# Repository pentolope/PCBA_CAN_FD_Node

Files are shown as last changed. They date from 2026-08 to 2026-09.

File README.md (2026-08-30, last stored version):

# CAN-FD Sensor/Control Node

General-purpose CAN-FD node for a 24 V industrial system: MCU with CAN-FD, external transceiver, switchable termination, four inputs, four low-side outputs.

This repository holds the design problem for `PCBA_CAN_FD_Node`, titled in metadata "CAN-FD Sensor/Control Node": a general-purpose CAN-FD node for a 24 V industrial system. The brief fixes the functional skeleton: a modern MCU with CAN-FD driving an external CAN-FD transceiver, switchable 120-ohm bus termination, ESD protection at the bus connector, reverse-polarity and transient protection on the 24 V input, an efficient local regulator, and four digital inputs plus four low-side outputs for demonstration loads. It also fixes one placement rule — the CAN connector must place CANH/CANL adjacent, with protection and termination kept near that connector. Everything else is open: no part, vendor, connector, package, regulator topology, rail voltage, bit rate, current rating, board outline, or stackup is named, and the layer count is only characterised in metadata as "2 or 4". The design agent must choose and justify those, documenting engineering decisions rather than treating them as pre-existing user requirements.

> **This board has not been designed.** There is no schematic, no layout and no
> part selection here — only the brief, a reading of the brief, and the
> scaffolding a design run needs. That is the intended state of this repository,
> not a gap in it.

## What the brief fixes, and what it leaves open

The brief pins down 14 requirements and deliberately leaves
20 decisions to whoever designs the board. The `Source` column says
which is which: `brief` is quoted from [BRIEF.md](BRIEF.md), `metadata` comes
from the benchmark catalogue, and `open` means the brief does not fix it.

| Aspect | Value | Source |
|---|---|---|
| Board identity | repo PCBA_CAN_FD_Node; title "CAN-FD Sensor/Control Node"; benchmark_id 6 | metadata |
| Board function | General-purpose CAN-FD node for a 24 V industrial system | brief |
| Category / difficulty / brief detail | industrial-network; difficulty 2/5; detail 3/5 | metadata |
| Likely layer count | 2 or 4 | metadata |
| Primary stressors | CAN differential pair, 24V input protection, termination, MCU clocking | metadata |
| Controller | A modern MCU with CAN-FD (no family, part or package named) | brief |
| Bus PHY | External CAN-FD transceiver, separate from the MCU | brief |
| Bus termination | Switchable 120-ohm termination | brief |
| Bus protection | ESD protection at the bus connector | brief |
| 24 V input protection | Reverse-polarity and transient protection on the 24 V input | brief |
| Local power conversion | An efficient local regulator (topology, input source, rails and ratings unstated) | brief |
| Digital inputs | Four | brief |
| Outputs | Four low-side outputs, for demonstration loads | brief |
| CAN connector arrangement and protection zone | CANH/CANL adjacent at the connector; protection and termination kept near the connector | brief |
| Board outline, connector types, rails, bit rates and specific part numbers | Not fixed by the brief - design agent's choice | open |

The full split, with the verbatim brief text substantiating every fixed
requirement, is in [board/requirements.md](board/requirements.md) and
machine-readably in [board/requirements.json](board/requirements.json).

**Missing details are design freedom, not permission to fabricate unstated user
requirements.** A choice the brief left open is recorded as a decision, with its
reasoning — never promoted into a requirement.

## Benchmark position

| | |
|---|---|
| Benchmark id | 6 of 32 |
| Category | industrial-network |
| Difficulty | 2 / 5 |
| Brief detail | 3 / 5 |
| Likely layer count | 2 or 4 |
| Primary stressors | CAN differential pair, 24V input protection, termination, MCU clocking |

At difficulty 2/5 and brief detail 3/5 in the `industrial-network` category, this board tests whether an agent can execute a well-understood industrial node without over-claiming: the named stressors are the CAN differential pair, 24 V input protection, termination, and MCU clocking. The brief is specific about block-level content and one connector-region placement rule, but deliberately silent on parts, rails, bit rates, ratings, geometry and stackup — so the benchmark measures how cleanly an agent separates the stated architecture from the many unstated choices, and whether it can substantiate a differential pair, a protection front end, and a clock accurate enough for CAN-FD bit timing with real evidence rather than assertion.

This repository is one of thirty-two. The suite, the protocol and the results
live in [PCBA_AutoDesignAndTest_Bench](https://github.com/pentolope/PCBA_AutoDesignAndTest_Bench).

## Repository layout

| Path | Contents |
|---|---|
| `BRIEF.md` | the supplied brief — authoritative, preserved byte for byte, never edited |
| `board/requirements.md` | what the brief fixes, what it leaves open, and where decisions get recorded |
| `board/requirements.json` | the same split, machine-readable, each fixed requirement bound to brief text |
| `board/manifest.template.json` | the toolkit's minimum manifest, pre-filled for this board |
| `board/toolchain.json` | where this board's build finds KiCad and the router |
| `benchmark/metadata.json` | the supplied catalogue entry — category, difficulty, detail, stressors |
| `docs/architecture.md` | the decisions this board must make, as questions, unanswered |
| `docs/sources.md` | the classes of evidence the design will have to cite |
| `docs/status.md` | what exists, what does not, and what is deliberately absent |
| `candidates/` | disposable search output, ignored by Git |
| `.claude/skills/` | the accountability-review skill [CLAUDE.md](CLAUDE.md) requires before a push |
| `tooling/PCBA_AutoDesignAndTest` | the shared verification/routing/release toolkit, as a pinned submodule |

## Getting the repository

The toolkit is a submodule and carries KiCad Routing Tools as a submodule of its
own, so clone recursively:

```bash
git clone --recursive https://github.com/pentolope/PCBA_CAN_FD_Node.git
```

```bash
git submodule update --init --recursive
```

## Designing the board

Generic verification, routing and release logic is **not** written here. It is
consumed from `tooling/PCBA_AutoDesignAndTest`, which is board-agnostic by
construction and must stay that way; this repository owns the board and nothing
else. Start from
[the toolkit's onboarding guide](tooling/PCBA_AutoDesignAndTest/examples/onboarding.md),
and see [CLAUDE.md](CLAUDE.md) for the rules a design run works under.

```bash
python3 tooling/PCBA_AutoDesignAndTest/run.py preflight
```

## Brief integrity

`BRIEF.md` SHA-256 `3897ccfaae068a75cbd3eae3186d01ac4c7f7dafd298f4a1a979556b659bc86c`

Every quotation in `board/requirements.json` is bound to those exact bytes. If
the brief ever changes, the bindings are stale by construction — which is the
point of recording the digest.

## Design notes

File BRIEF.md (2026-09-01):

# PCBA_CAN_FD_Node — CAN-FD Sensor/Control Node
## Design brief

Design a general-purpose CAN-FD node for a 24 V industrial system. Use a modern MCU with CAN-FD, an external CAN-FD transceiver, switchable 120-ohm termination, ESD protection at the bus connector, reverse-polarity and transient protection on the 24 V input, and an efficient local regulator. Provide four digital inputs and four low-side outputs for demonstration loads. The CAN connector must place CANH/CANL adjacent and keep protection/termination near the connector.

## Functional requirements

- With only the 24 V input and the CAN connector attached, the board shall pass bus traffic, read all four inputs and drive all four outputs.
- The MCU shall reach the bus only through the external transceiver; classical CAN and CAN-FD shall both be supported, and the maximum qualified data-phase rate stated.

## Power input and protection

- The continuous 24 V input range shall be stated, with every part in that path rated above it with margin.
- Reverse polarity at that magnitude shall not damage the board or latch, and transients shall be clamped below the rating of everything behind the input.
- Conversion to the logic rail(s) shall not dissipate the full input-to-output difference at load; the transceiver shall get the supply voltage its datasheet requires.

## CAN interface and termination

- CANH and CANL shall occupy adjacent connector contacts, with no other contact between them.
- Termination shall be a nominal 120 Ω differential load when enabled and switchable to fully removed without unsoldering parts.
- Bus protection shall meet the declared IEC 61000-4-2 level, be balanced line to line, and add no more capacitance than the qualified rate allows.
- The bus fault voltage withstood shall be stated and shall cover CANH or CANL shorted to ground or to the node's own 24 V.

## Digital inputs and low-side outputs

- Each input shall have a stated threshold and hysteresis and a defined state with its terminal open.
- Each input shall survive, continuously, any voltage from 0 V to the maximum rated 24 V input, in either polarity.
- Each output shall switch independently, be off from power-on until firmware drives it, and clamp inductive turn-off energy within its rating, at the stated per-channel current with all four on.

## Placement and layout

- Bus protection shall be first in the path from the connector contacts, termination immediately behind it, with no bus trace reaching elsewhere first.
- CANH/CANL shall be a coupled pair of constant spacing over an unbroken return path, with no stubs, and discharge return shall reach the connector's reference by a short, low-inductance path.

## Test and bring-up

- Programming and debug shall be on a labelled footprint usable with the board powered and the bus mated.
- Test points shall be provided on each rail, on CANH and CANL, and on the transceiver's TXD/RXD pair.

## Open choices

- MCU and transceiver selection, subject to an integrated CAN-FD controller, the I/O count above, and the declared rate and fault ratings.
- Whether termination switches manually or under MCU control, and the connector families and rail voltages that follow.

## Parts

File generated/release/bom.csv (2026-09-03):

Quantity | Designator | Comment | Footprint | LCSC Part #
1 | C1 | 47uF | Capacitor_SMD:CP_Elec_6.3x7.7 | C47023121
10 | C2,C3,C8,C10,C11,C12,C13,C15,C18,C19 | 100nF | Capacitor_SMD:C_0603_1608Metric | C113803
2 | C4,C5 | 1uF/100V | Capacitor_SMD:C_1206_3216Metric | C70463
3 | C6,C7,C9 | 10uF | Capacitor_SMD:C_0805_2012Metric | C326595
1 | C14 | 1uF | Capacitor_SMD:C_0603_1608Metric | C106858
2 | C16,C17 | 15pF | Capacitor_SMD:C_0603_1608Metric | C107037
1 | C20 | 4.7nF | Capacitor_SMD:C_0603_1608Metric | C115052
4 | C21,C22,C23,C24 | 10nF | Capacitor_SMD:C_0603_1608Metric | C107059
1 | D1 | SMAJ30CA | Diode_SMD:D_SMA | C110043
1 | D2 | BZT52C12 | Diode_SMD:D_SOD-123 | C173429
1 | D3 | B1100 | Diode_SMD:D_SMA | C110106
1 | D4 | ESDCAN05-2BWY | Package_TO_SOT_SMD:SOT-323_SC-70 | C1973137
4 | D5,D6,D7,D8 | 1N4148W | Diode_SMD:D_SOD-123 | C81598
4 | D9,D10,D11,D12 | SMF30A | CanFdNode:D_SOD-123FL_1.2x1.2mm_P3.2mm | C364281
1 | D13 | KT-0603R | LED_SMD:LED_0603_1608Metric | C2286
1 | F1 | 1812L200/33GR | CanFdNode:PTC_1812_LUTE_1812L | C18198343
1 | J1 | DB128V-5.08-2P-GN-S | CanFdNode:TerminalBlock_DB128V-5.08_1x02_P5.08mm | C2915639
1 | J2 | DB128V-5.08-3P-GN-S | CanFdNode:TerminalBlock_DB128V-5.08_1x03_P5.08mm | C2915640
2 | J3,J4 | DB128V-5.08-5P-GN-S | CanFdNode:TerminalBlock_DB128V-5.08_1x05_P5.08mm | C2927513
1 | J5 | KH-2.54PH180-1X5P-L11.5 | Connector_PinHeader_2.54mm:PinHeader_1x05_P2.54mm_Vertical | C2932699
2 | J6,J7 | KH-2.54PH180-1X2P-L11.5 | Connector_PinHeader_2.54mm:PinHeader_1x02_P2.54mm_Vertical | C2905434
1 | L1 | 47uH | CanFdNode:Inductor_Sunlord_SWPA5040 | C86617
1 | Q1 | NCE6003X | Package_TO_SOT_SMD:SOT-23 | C2934580
4 | Q2,Q3,Q4,Q5 | WST6066A | Package_TO_SOT_SMD:SOT-23 | C148352
9 | R1,R14,R15,R16,R17,R30,R31,R32,R33 | 100k | Resistor_SMD:R_0603_1608Metric | C25803
1 | R2 | 124k | Resistor_SMD:R_0603_1608Metric | C22788
1 | R3 | 23.7k | Resistor_SMD:R_0603_1608Metric | C22912
1 | R4 | 470k | Resistor_SMD:R_0603_1608Metric | C23178
1 | R5 | 56k | Resistor_SMD:R_0603_1608Metric | C23206
1 | R6 | 2.7k | Resistor_SMD:R_0603_1608Metric | C13167
6 | R7,R8,R22,R23,R24,R25 | 10k | Resistor_SMD:R_0603_1608Metric | C25804
2 | R9,R10 | 60.4R | Resistor_SMD:R_2512_6332Metric | C3994751
1 | R11 | 470R | Resistor_SMD:R_0603_1608Metric | C23179
6 | R12,R13,R26,R27,R28,R29 | 100R | Resistor_SMD:R_0603_1608Metric | C22775
4 | R18,R19,R20,R21 | 20k | Resistor_SMD:R_0603_1608Metric | C4184
1 | U1 | STM32G431KBT6 | Package_QFP:LQFP-32_7x7mm_P0.8mm | C529357
1 | U2 | TCAN1042HGVDR | Package_SO:SOIC-8_3.9x4.9mm_P1.27mm | C124014
1 | U3 | MP2459GJ-Z | Package_TO_SOT_SMD:TSOT-23-6 | C39578
1 | U4 | HT75R33-1A | Package_TO_SOT_SMD:SOT-89-3 | C53223865
1 | Y1 | 8MHz | CanFdNode:Crystal_YXC_YSX531SL_5.0x3.2mm | C19711736

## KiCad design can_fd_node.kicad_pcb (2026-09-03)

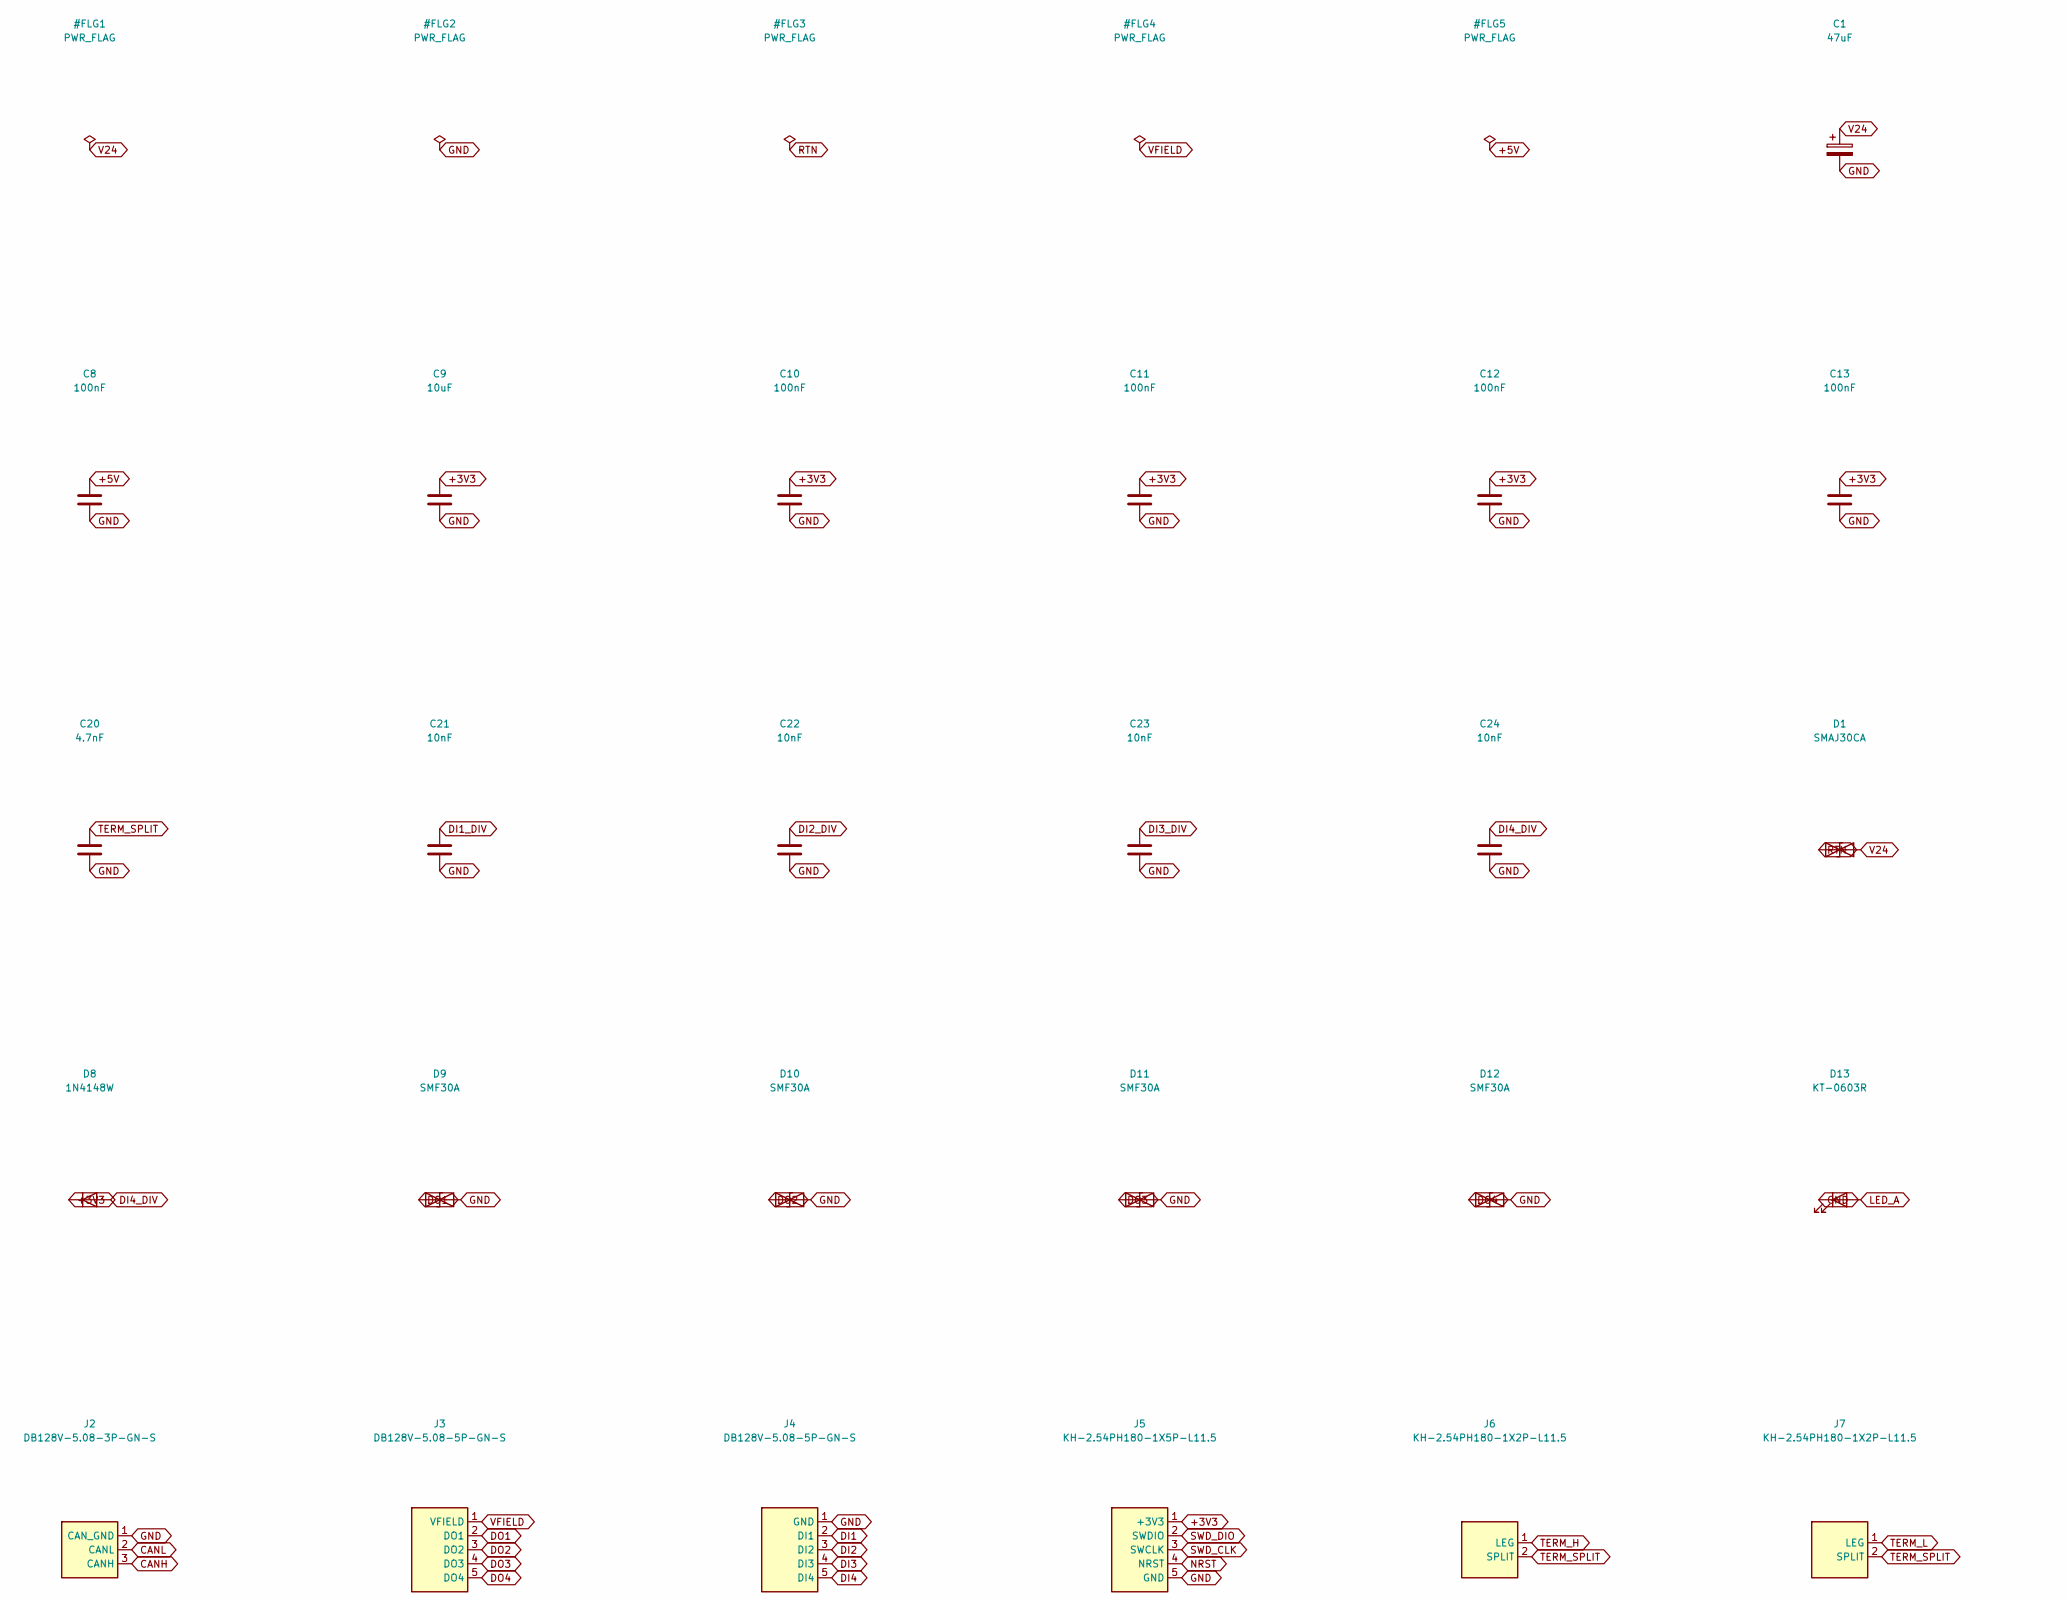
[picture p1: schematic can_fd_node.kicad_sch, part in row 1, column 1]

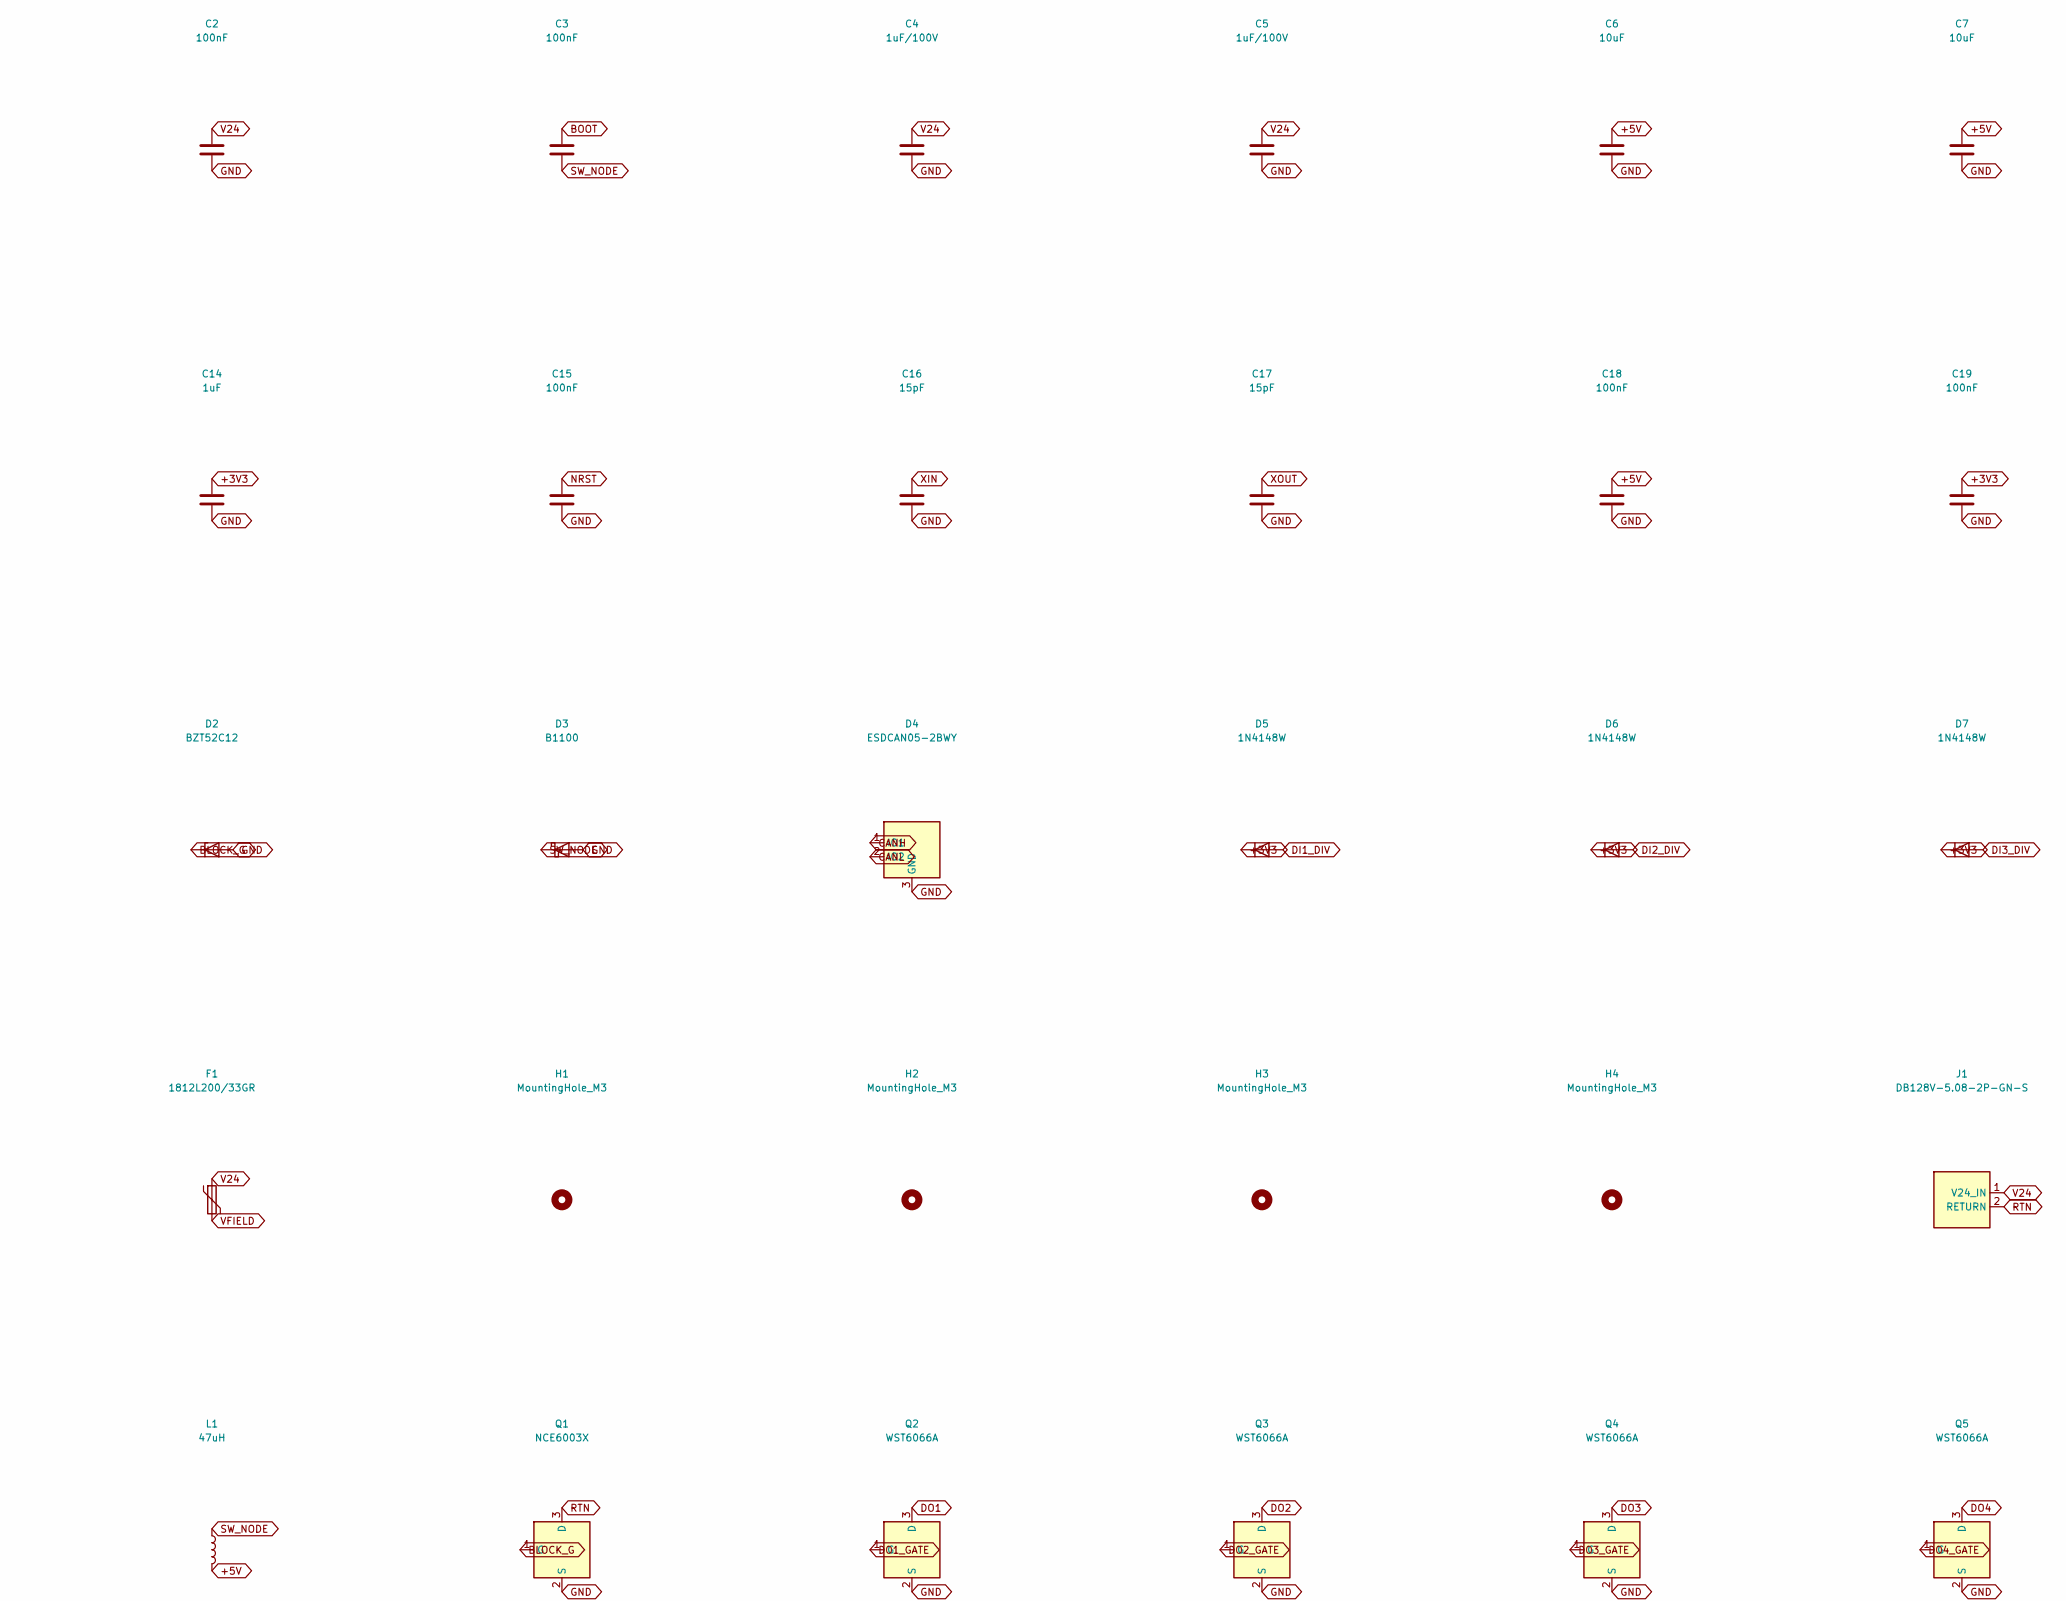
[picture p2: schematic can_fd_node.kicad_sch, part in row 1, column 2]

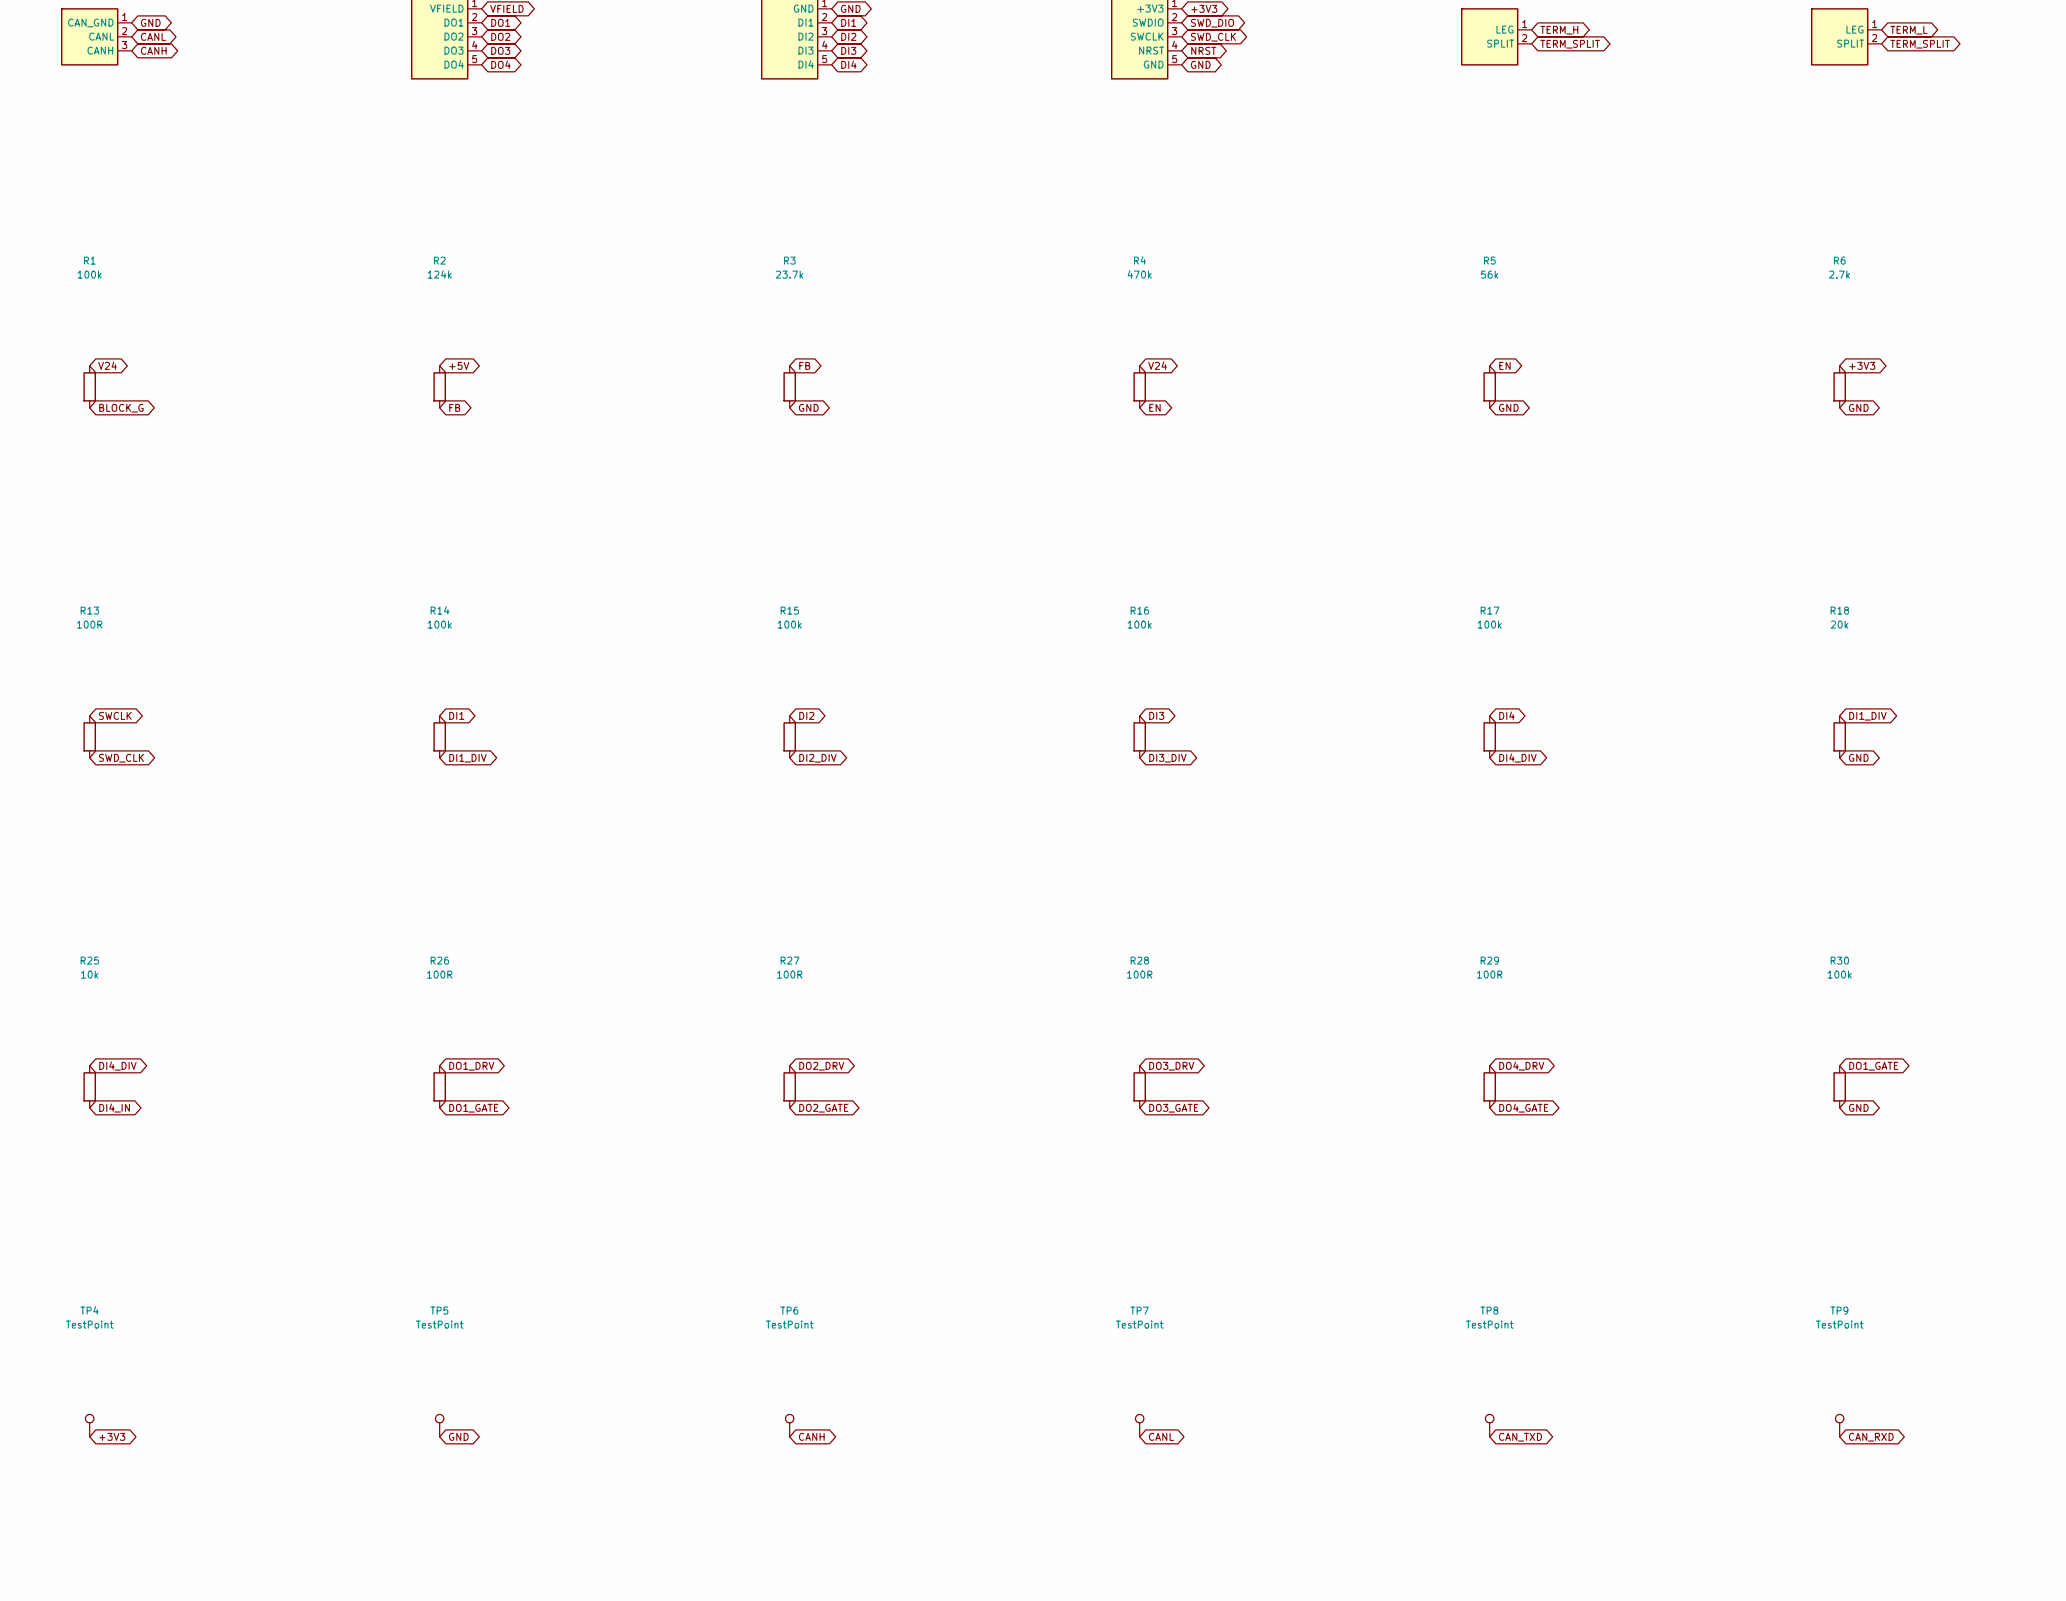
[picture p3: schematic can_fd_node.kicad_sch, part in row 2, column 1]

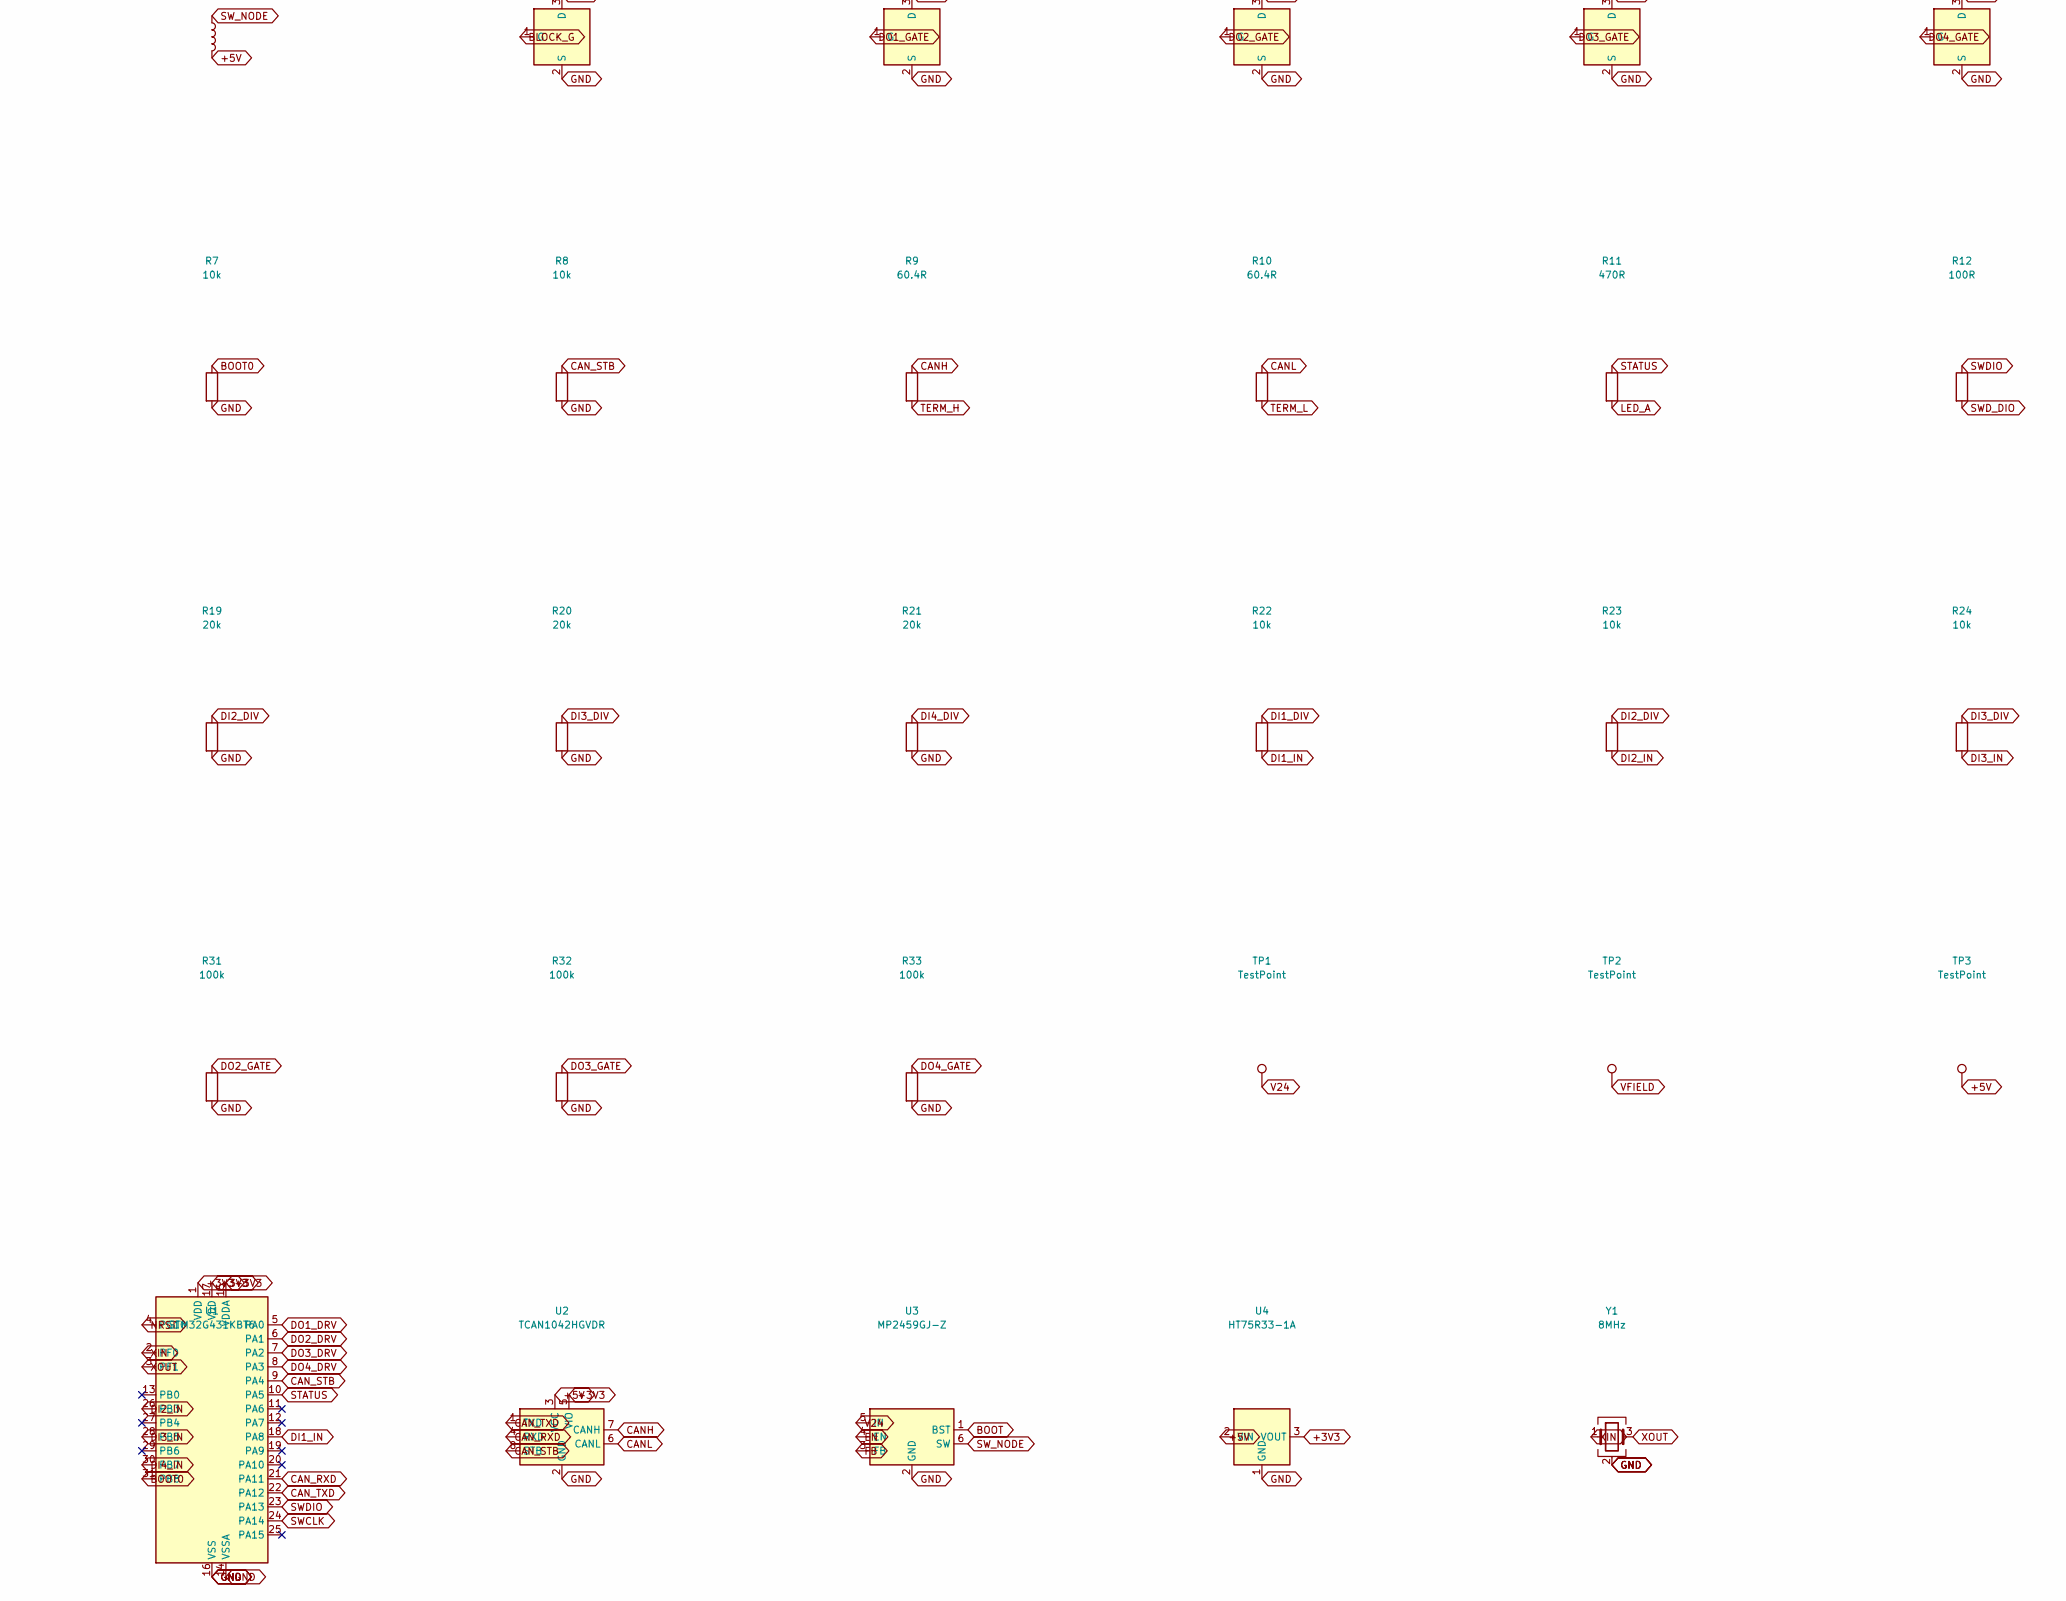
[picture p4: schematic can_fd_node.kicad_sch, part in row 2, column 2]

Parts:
C1: 47uF; CP_Elec_6.3x7.7; MPN RVT63V47M6X8; LCSC C47023121
C2, C3, C8, C10, C11, C12, C13, C15, C18, C19: 100nF; C_0603_1608Metric; MPN CC0603KRX7R0BB104; LCSC C113803
C4, C5: 1uF/100V; C_1206_3216Metric; MPN CC1206KKX7R0BB105; LCSC C70463
C6, C7, C9: 10uF; C_0805_2012Metric; MPN CC0805KKX7R7BB106; LCSC C326595
C14: 1uF; C_0603_1608Metric; MPN CC0603KRX7R8BB105; LCSC C106858
C16, C17: 15pF; C_0603_1608Metric; MPN CC0603JRNPO9BN150; LCSC C107037
C20: 4.7nF; C_0603_1608Metric; MPN CC0603KRX7R0BB472; LCSC C115052
C21, C22, C23, C24: 10nF; C_0603_1608Metric; MPN CC0603KRX7R0BB103; LCSC C107059
D1: SMAJ30CA; D_SMA; MPN SMAJ30CA; LCSC C110043
D2: BZT52C12; D_SOD-123; MPN BZT52C12; LCSC C173429
D3: B1100; D_SMA; MPN B1100-13-F; LCSC C110106
D4: ESDCAN05-2BWY; SOT-323_SC-70; MPN ESDCAN05-2BWY; LCSC C1973137
D5, D6, D7, D8: 1N4148W; D_SOD-123; MPN 1N4148W; LCSC C81598
D9, D10, D11, D12: SMF30A; D_SOD-123FL_1.2x1.2mm_P3.2mm; MPN SMF30A; LCSC C364281
D13: KT-0603R; LED_0603_1608Metric; MPN KT-0603R; LCSC C2286
F1: 1812L200/33GR; PTC_1812_LUTE_1812L; MPN 1812L200/33GR; LCSC C18198343
H1, H2, H3, H4: MountingHole_M3; MountingHole_3.2mm_M3
J1: DB128V-5.08-2P-GN-S; TerminalBlock_DB128V-5.08_1x02_P5.08mm; MPN DB128V-5.08-2P-GN-S; LCSC C2915639
J2: DB128V-5.08-3P-GN-S; TerminalBlock_DB128V-5.08_1x03_P5.08mm; MPN DB128V-5.08-3P-GN-S; LCSC C2915640
J3, J4: DB128V-5.08-5P-GN-S; TerminalBlock_DB128V-5.08_1x05_P5.08mm; MPN DB128V-5.08-5P-GN-S; LCSC C2927513
J5: KH-2.54PH180-1X5P-L11.5; PinHeader_1x05_P2.54mm_Vertical; MPN KH-2.54PH180-1X5P-L11.5; LCSC C2932699
J6, J7: KH-2.54PH180-1X2P-L11.5; PinHeader_1x02_P2.54mm_Vertical; MPN KH-2.54PH180-1X2P-L11.5; LCSC C2905434
L1: 47uH; Inductor_Sunlord_SWPA5040; MPN SWPA5040S470MT; LCSC C86617
Q1: NCE6003X; SOT-23; MPN NCE6003X; LCSC C2934580
Q2, Q3, Q4, Q5: WST6066A; SOT-23; MPN WST6066A; LCSC C148352
R1, R14, R15, R16, R17, R30, R31, R32, R33: 100k; R_0603_1608Metric; MPN 0603WAF1003T5E; LCSC C25803
R2: 124k; R_0603_1608Metric; MPN 0603WAF1243T5E; LCSC C22788
R3: 23.7k; R_0603_1608Metric; MPN 0603WAF2372T5E; LCSC C22912
R4: 470k; R_0603_1608Metric; MPN 0603WAF4703T5E; LCSC C23178
R5: 56k; R_0603_1608Metric; MPN 0603WAF5602T5E; LCSC C23206
R6: 2.7k; R_0603_1608Metric; MPN 0603WAF2701T5E; LCSC C13167
R7, R8, R22, R23, R24, R25: 10k; R_0603_1608Metric; MPN 0603WAF1002T5E; LCSC C25804
R9, R10: 60.4R; R_2512_6332Metric; MPN RMCF2512FT60R4; LCSC C3994751
R11: 470R; R_0603_1608Metric; MPN 0603WAF4700T5E; LCSC C23179
R12, R13, R26, R27, R28, R29: 100R; R_0603_1608Metric; MPN 0603WAF1000T5E; LCSC C22775
R18, R19, R20, R21: 20k; R_0603_1608Metric; MPN 0603WAF2002T5E; LCSC C4184
TP1, TP2, TP3, TP4, TP5, TP6, TP7, TP8, TP9: TestPoint; TestPoint_Pad_D1.0mm
U1: STM32G431KBT6; LQFP-32_7x7mm_P0.8mm; MPN STM32G431KBT6; LCSC C529357
U2: TCAN1042HGVDR; SOIC-8_3.9x4.9mm_P1.27mm; MPN TCAN1042HGVDR; LCSC C124014
U3: MP2459GJ-Z; TSOT-23-6; MPN MP2459GJ-Z; LCSC C39578
U4: HT75R33-1A; SOT-89-3; MPN HT75R33-1A; LCSC C53223865
Y1: 8MHz; Crystal_YXC_YSX531SL_5.0x3.2mm; MPN XL1EL89CMI-111YLC-8M; LCSC C19711736

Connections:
+3V3: C9.1, C10.1, C11.1, C12.1, C13.1, C14.1, C19.1, D5.1 (K), D6.1 (K), D7.1 (K), D8.1 (K), J5.1 (+3V3), R6.1, TP4.1, U1.1 (VDD), U1.15 (VDDA), U1.17 (VDD), U2.5 (VIO), U4.3 (VOUT)
+5V: C6.1, C7.1, C8.1, C18.1, L1.2, R2.1, TP3.1, U2.3 (VCC), U4.2 (VIN)
BLOCK_G: D2.1 (K), Q1.1 (G), R1.2
BOOT: C3.1, U3.1 (BST)
BOOT0: R7.1, U1.31 (PB8)
CANH: D4.1 (IO1), J2.3 (CANH), R9.1, TP6.1, U2.7 (CANH)
CANL: D4.2 (IO2), J2.2 (CANL), R10.1, TP7.1, U2.6 (CANL)
CAN_RXD: TP9.1, U1.21 (PA11), U2.4 (RXD)
CAN_STB: R8.1, U1.9 (PA4), U2.8 (STB)
CAN_TXD: TP8.1, U1.22 (PA12), U2.1 (TXD)
DI1: J4.2 (DI1), R14.1
DI1_DIV: C21.1, D5.2 (A), R14.2, R18.1, R22.1
DI1_IN: R22.2, U1.18 (PA8)
DI2: J4.3 (DI2), R15.1
DI2_DIV: C22.1, D6.2 (A), R15.2, R19.1, R23.1
DI2_IN: R23.2, U1.26 (PB3)
DI3: J4.4 (DI3), R16.1
DI3_DIV: C23.1, D7.2 (A), R16.2, R20.1, R24.1
DI3_IN: R24.2, U1.28 (PB5)
DI4: J4.5 (DI4), R17.1
DI4_DIV: C24.1, D8.2 (A), R17.2, R21.1, R25.1
DI4_IN: R25.2, U1.30 (PB7)
DO1: D9.1 (A1), J3.2 (DO1), Q2.3 (D)
DO1_DRV: R26.1, U1.5 (PA0)
DO1_GATE: Q2.1 (G), R26.2, R30.1
DO2: D10.1 (A1), J3.3 (DO2), Q3.3 (D)
DO2_DRV: R27.1, U1.6 (PA1)
DO2_GATE: Q3.1 (G), R27.2, R31.1
DO3: D11.1 (A1), J3.4 (DO3), Q4.3 (D)
DO3_DRV: R28.1, U1.7 (PA2)
DO3_GATE: Q4.1 (G), R28.2, R32.1
DO4: D12.1 (A1), J3.5 (DO4), Q5.3 (D)
DO4_DRV: R29.1, U1.8 (PA3)
DO4_GATE: Q5.1 (G), R29.2, R33.1
EN: R4.2, R5.1, U3.4 (EN)
FB: R2.2, R3.1, U3.3 (FB)
GND: C1.2, C2.2, C4.2, C5.2, C6.2, C7.2, C8.2, C9.2, C10.2, C11.2, C12.2, C13.2, C14.2, C15.2, C16.2, C17.2, C18.2, C19.2, C20.2, C21.2, C22.2, C23.2, C24.2, D2.2 (A), D3.2 (A), D4.3 (GND), D9.2 (A2), D10.2 (A2), D11.2 (A2), D12.2 (A2), D13.1 (K), J2.1 (CAN_GND), J4.1 (GND), J5.5 (GND), Q1.2 (S), Q2.2 (S), Q3.2 (S), Q4.2 (S), Q5.2 (S), R3.2, R5.2, R6.2, R7.2, R8.2, R18.2, R19.2, R20.2, R21.2, R30.2, R31.2, R32.2, R33.2, TP5.1, U1.14 (VSSA), U1.16 (VSS), U1.32 (VSS), U2.2 (GND), U3.2 (GND), U4.1 (GND), Y1.2 (G), Y1.4 (G)
LED_A: D13.2 (A), R11.2
NRST: C15.1, J5.4 (NRST), U1.4 (PG10)
RTN: D1.1 (A1), J1.2 (RETURN), Q1.3 (D)
STATUS: R11.1, U1.10 (PA5)
SWCLK: R13.1, U1.24 (PA14)
SWDIO: R12.1, U1.23 (PA13)
SWD_CLK: J5.3 (SWCLK), R13.2
SWD_DIO: J5.2 (SWDIO), R12.2
SW_NODE: C3.2, D3.1 (K), L1.1, U3.6 (SW)
TERM_H: J6.1 (LEG), R9.2
TERM_L: J7.1 (LEG), R10.2
TERM_SPLIT: C20.1, J6.2 (SPLIT), J7.2 (SPLIT)
V24: C1.1, C2.1, C4.1, C5.1, D1.2 (A2), F1.1, J1.1 (V24_IN), R1.1, R4.1, TP1.1, U3.5 (IN)
VFIELD: F1.2, J3.1 (VFIELD), TP2.1
XIN: C16.1, U1.2 (PF0), Y1.1
XOUT: C17.1, U1.3 (PF1), Y1.3

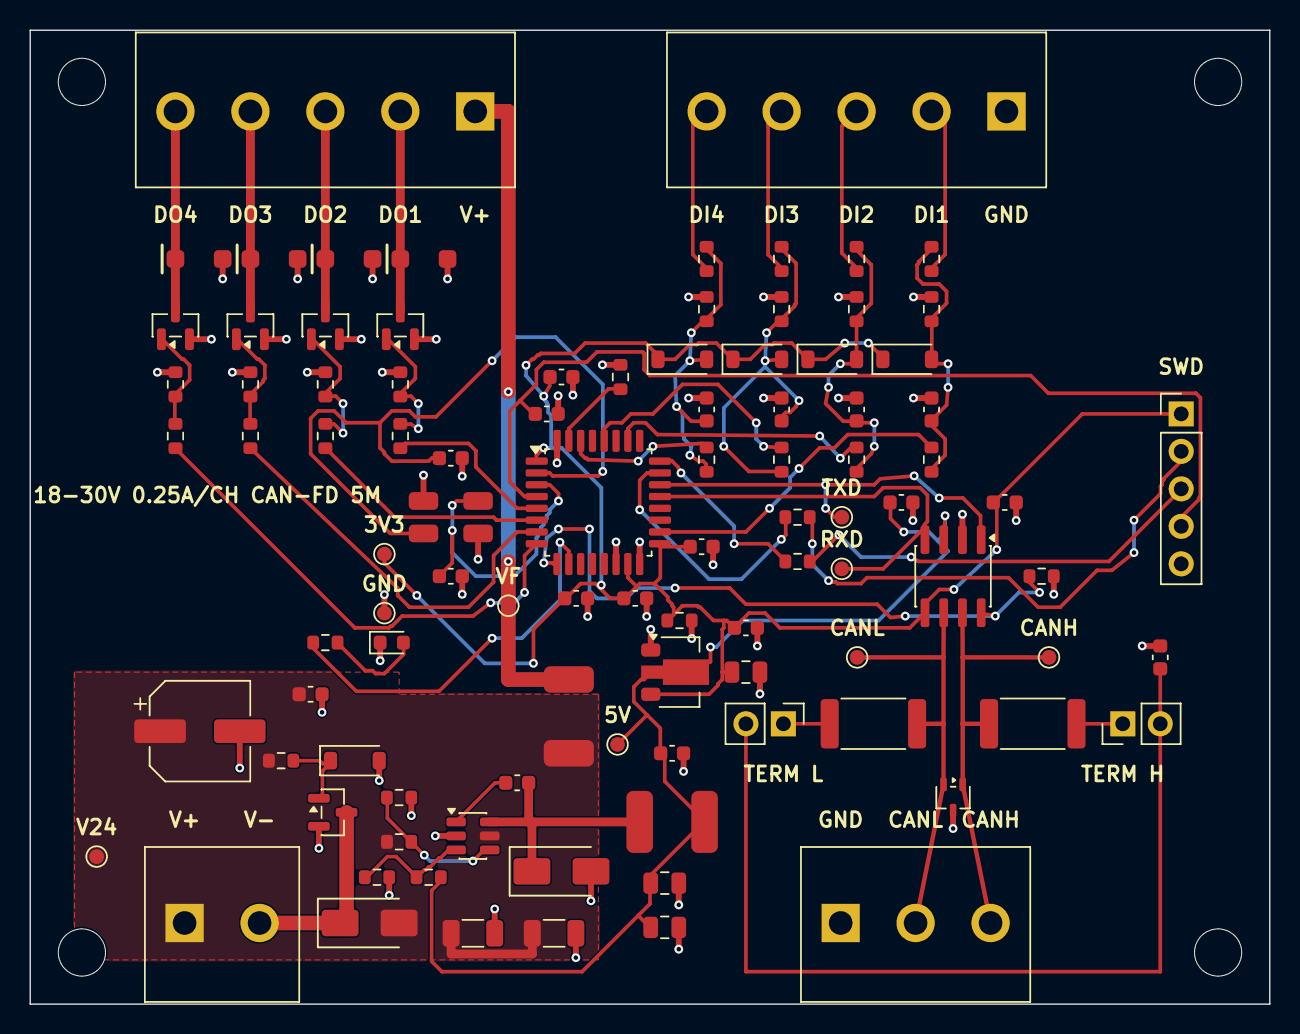
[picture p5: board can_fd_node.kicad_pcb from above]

Board: 2 copper layers, 84.0 x 66.0 mm, 102 parts (0 on the bottom side), 53 nets.

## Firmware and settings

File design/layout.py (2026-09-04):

"""The board: outline, placement, pours and silkscreen, from the design source.

Board coordinates run x right and y UP from the lower-left corner, which is
the frame every dimension in this module is stated in. KiCad's own y runs
down, so the mapping is applied once, here.

The arrangement follows the two things that must not be compromised. The bus
enters at the bottom right and meets its protection, then its termination,
then the transceiver, in that order and in a straight line, over ground that
nothing is allowed to cut. Everything the field carries enters at the two
edges: the supply and the bus along the bottom, the field inputs and outputs
along the top, so no field conductor crosses the controller. The controller
sits between them, and the power chain runs along the bottom-left from the
supply terminal to the two logic rails.
"""
from __future__ import annotations

import json
import math
import os
import sys

from . import ksym, netlist

_TOOLKIT = os.path.join(
    os.path.dirname(os.path.dirname(os.path.abspath(__file__))),
    "tooling", "PCBA_AutoDesignAndTest")
if _TOOLKIT not in sys.path:
    sys.path.insert(0, _TOOLKIT)

from pcbqa import headless  # noqa: E402

headless.suppress_blocking_ui()

from pcbqa import board as pcbqa_board  # noqa: E402

import pcbnew  # noqa: E402

REPO_ROOT = os.path.dirname(os.path.dirname(os.path.abspath(__file__)))
BOARD_PATH = os.path.join(REPO_ROOT, netlist.PROJECT_NAME + ".kicad_pcb")
PLACEMENT_PATH = os.path.join(REPO_ROOT, "constraints", "placement.json")

FOOTPRINT_SEARCH_PATHS = (
    os.path.join(REPO_ROOT, "library"),
    "/usr/share/kicad/footprints",
)

ORIGIN_MM = (30.0, 110.0)

BOARD_W_MM = 84.0
BOARD_H_MM = 66.0

EDGE_WIDTH_MM = 0.1
TRACK_WIDTH_MM = 0.25
#: Width of the generated field-supply and field-output conductors. Sized for
#: one channel's rating and, on the supply, for all four at once.
POWER_TRACK_WIDTH_MM = 0.6
FIELD_TRACK_WIDTH_MM = 1.0
#: Width of the generated bus pair, and the gap between the two conductors.
#: The pair is drawn rather than searched: constant spacing over unbroken
#: ground is a requirement, and a search has no freedom left inside it.
BUS_TRACK_WIDTH_MM = 0.3
BUS_GAP_MM = 0.3
CLEARANCE_MM = 0.15
EDGE_CLEARANCE_MM = 0.3
VIA_DIAMETER_MM = 0.6
VIA_DRILL_MM = 0.3
ZONE_INSET_MM = 0.5
STITCH_TRACK_WIDTH_MM = 0.4
#: How far a stitch's own annulus stands off the pad it bonds to. It is a
#: mask-opening figure, not a copper one: a via whose annulus touches the
#: opening of a pad that receives paste is a place for solder to wick away
#: down the barrel, and the board's own via-to-mask target is what this
#: keeps.
STITCH_GAP_MM = 0.45
#: The board's own via-to-mask-opening target, which a generated via is
#: held to as well as a routed one.
VIA_MASK_TARGET_MM = 0.15

#: Field terminal blocks sit with their wire entry on the board edge; the pin
#: row stands this far inside it.
TERMINAL_PIN_INSET_MM = 5.5
TERMINAL_PITCH_MM = 5.08

#: Where each connector's pin row sits.
BOTTOM_ROW_Y_MM = TERMINAL_PIN_INSET_MM
TOP_ROW_Y_MM = BOARD_H_MM - TERMINAL_PIN_INSET_MM

#: The one lane between the crystal and the controller. The field supply
#: runs up it, which is the only way it reaches the output connector's
#: supply contact without crossing a channel.
FIELD_CORRIDOR_X_MM = 32.4

SUPPLY_TERMINAL_X_MM = 12.0
BUS_TERMINAL_X_MM = 60.0
OUTPUT_TERMINAL_X_MM = 20.0
INPUT_TERMINAL_X_MM = 56.0

#: The bus corridor: the pair runs straight up this line from the connector,
#: through the protection and the termination tap, to the transceiver. The
#: corridor is the midpoint of the connector's own two bus contacts, so the
#: fan-in from the terminal block's 5.08 pitch is symmetric.
BUS_CORRIDOR_X_MM = BUS_TERMINAL_X_MM + TERMINAL_PITCH_MM / 2.0
#: Separation of the two conductors, which is the transceiver's own pad
#: separation: the pair arrives at the pads it is drawn for and nothing has
#: to fan out at the end of the run.
BUS_PAIR_SEPARATION_MM = 1.27
BUS_PROTECTOR_Y_MM = 14.0
BUS_TERMINATION_Y_MM = 19.0
BUS_LINK_X_OFFSET_MM = 11.5
BUS_TRANSCEIVER_Y_MM = 29.0
#: The centre of the split termination carries no differential current, so
#: it is the one conductor that may take the long way round: it runs along
#: the bottom of the board, below the connector's contacts, where it crosses
#: neither bus conductor.
BUS_SPLIT_RETURN_Y_MM = 2.2

#: The back-layer copper under the pair, between one station and the next.
#: Nothing may cut it, so the stretches between the parts are rule areas
#: rather than a hope. The stations themselves are left out, and so is the
#: stretch immediately below the protector: that is where the protector's
#: own reference via goes, and a via on the reference net ties the pour
#: together rather than cutting it - which is the whole point of the short
#: return path the brief asks for there.
BUS_KEEPOUT_HALF_WIDTH_MM = 1.6
BUS_KEEPOUT_SPANS_MM = ((8.0, 11.2), (15.7, 17.6), (20.4, 22.4),
                        (24.6, BUS_TRANSCEIVER_Y_MM - 3.2))

#: Rows inside a field-output column, from the connector down.
OUTPUT_ROWS_MM = {"clamp": 50.5, "switch": 46.0, "gate": 42.0,
                  "series": 38.5}
#: Rows inside a field-input column, from the connector down.
INPUT_ROWS_MM = {"upper": 50.5, "lower": 47.1, "clamp": 43.7,
                 "filter": 40.3, "series": 36.9}
#: How far a channel's clamp stands off its own lane. The clamp's other
#: terminal is the reference, and it belongs beside the lane rather than in
#: it: the conductor that carries the channel's current runs straight up the
#: lane through the clamp's first pad and reaches the contact without
#: stepping round anything.
OUTPUT_CLAMP_OFFSET_MM = 1.60
INPUT_CLAMP_OFFSET_MM = -1.65

MOUNTING_HOLES_MM = {
    "H1": (3.5, 3.5),
    "H2": (BOARD_W_MM - 3.5, 3.5),
    "H3": (3.5, BOARD_H_MM - 3.5),
    "H4": (BOARD_W_MM - 3.5, BOARD_H_MM - 3.5),
}

#: Parts a placement search may not move, and why.
#:
#: The connectors and the fasteners are the board's mechanical contract. The
#: test points are its service contract. The bus protector, the termination
#: and the transceiver are the one chain whose order the brief fixes, and the
#: pair between them is generated copper, so their positions are the topology
#: rather than an input to it.
LOCKED_REFERENCES = tuple(sorted(
    [reference for reference in netlist.PARTS
     if reference[0] in ("J", "H") and reference[1:].isdigit()]
    + [reference for reference in netlist.PARTS
       if reference.startswith("TP")]
    + ["U2", "D4", "R9", "R10", "C20"]))


def connector_pin_x(reference, pin):
    """Where one contact of a bottom- or top-edge terminal block sits.

    The top-edge blocks face outward, so they are turned round and their
    contacts run right to left. A channel column stands under its own
    contact, so the column positions are read from here rather than declared
    a second time and left to drift.
    """
    centre, _y, rotation = SHARED_PLACEMENT[reference]
    count = len(netlist.CONNECTOR_PIN_ORDER[reference])
    span = TERMINAL_PITCH_MM * (count - 1) / 2.0
    offset = -span + TERMINAL_PITCH_MM * (pin - 1)
    return centre + (offset if rotation == 0.0 else -offset)


def _output_lane_x(channel):
    return connector_pin_x("J3", channel + 1)


def _input_lane_x(channel):
    return connector_pin_x("J4", channel + 1)


def _output_seed(channel):
    """One field-output column: clamp, switch, then the gate network.

    Every part stands in the 5.08 lane its own contact occupies, so a
    channel's current never crosses another channel's.
    """
    x = _output_lane_x(channel)
    rows = OUTPUT_ROWS_MM
    return {
        "D%d" % (channel + 8): (x + OUTPUT_CLAMP_OFFSET_MM, rows["clamp"],
                                0.0),
        "Q%d" % (channel + 1): (x, rows["switch"], 90.0),
        "R%d" % (channel + 29): (x, rows["gate"], 90.0),
        "R%d" % (channel + 25): (x, rows["series"], 90.0),
    }


def _input_seed(channel):
    """One field-input column: divider, clamp, filter and series element."""
    x = _input_lane_x(channel)
    rows = INPUT_ROWS_MM
    return {
        "R%d" % (channel + 13): (x, rows["upper"], 90.0),
        "R%d" % (channel + 17): (x, rows["lower"], 90.0),
        "D%d" % (channel + 4): (x + INPUT_CLAMP_OFFSET_MM, rows["clamp"],
                                0.0),
        "C%d" % (channel + 20): (x, rows["filter"], 90.0),
        "R%d" % (channel + 21): (x, rows["series"], 90.0),
    }


#: Everything that is not part of a field channel, left to right and bottom
#: to top: the supply terminal and its protection, the converter and its
#: regulator, the controller and its crystal, and the bus chain.
SHARED_PLACEMENT = {
    # the supply terminal, its clamp and the reverse-blocking device, which
    # sits in the return so the bus connector's reference pin can be the
    # board's own
    "J1": (13.0, BOTTOM_ROW_Y_MM, 0.0),
    "D1": (23.0, BOTTOM_ROW_Y_MM, 0.0),
    "Q1": (20.5, 13.0, 0.0),
    "R1": (17.0, 16.5, 0.0),
    "D2": (22.0, 16.5, 0.0),
    "C1": (11.5, 18.5, 0.0),
    "C2": (19.0, 21.0, 0.0),
    "TP1": (4.5, 10.0, 0.0),
    # the step-down converter. Its order along the board is the order of the
    # switching loop: the input capacitors, the converter, the catch diode,
    # the inductor, the output capacitors. The loop that carries the
    # switched current is the input capacitors, the converter's input and
    # switch pins, the diode and the reference, and it is that loop, not the
    # schematic, that decides these positions: the diode stands one
    # footprint from the converter and directly above the input capacitors,
    # so the loop encloses a few square millimetres of the reference plane
    # beneath it rather than the width of the board.
    "C4": (30.0, 4.8, 0.0),
    "C5": (35.5, 4.8, 0.0),
    "U3": (30.0, 11.4, 0.0),
    "R4": (25.0, 11.0, 0.0),
    "R5": (25.0, 14.0, 0.0),
    "D3": (36.0, 9.0, 0.0),
    "L1": (43.5, 12.35, 0.0),
    "C3": (33.0, 15.0, 0.0),
    # the feedback divider stands away from the switch node and the
    # bootstrap capacitor, on the quiet side of the converter, so the node
    # the converter regulates on runs beside neither of them. What is long
    # is instead the sense conductor from the output, which is a rail.
    "R2": (27.0, 8.6, 180.0),
    "R3": (23.5, 8.6, 0.0),
    # the output capacitors stay clear of the lane the termination's centre
    # node comes down in, which owns the column outboard of the links
    "C6": (43.0, 5.2, 0.0),
    "C7": (43.0, 8.2, 0.0),
    "C8": (43.5, 17.0, 0.0),
    "TP3": (39.8, 17.6, 0.0),
    # the logic regulator and the indicator
    "U4": (44.0, 22.5, 0.0),
    "C9": (48.5, 22.5, 0.0),
    "C10": (48.5, 25.5, 0.0),
    "R6": (44.0, 26.0, 0.0),
    "TP4": (24.0, 30.5, 0.0),
    "TP5": (24.0, 26.5, 0.0),
    "R11": (20.0, 24.5, 0.0),
    "D13": (24.5, 24.5, 0.0),
    # the controller, its crystal and its debug port
    "U1": (38.5, 34.0, 0.0),
    "C11": (36.0, 42.5, 0.0),
    "C12": (45.5, 31.0, 0.0),
    "C13": (37.0, 27.5, 0.0),
    "C14": (41.0, 27.5, 0.0),
    "C15": (35.0, 40.0, 0.0),
    "Y1": (28.5, 33.0, 0.0),
    "C16": (28.5, 37.0, 0.0),
    "C17": (28.5, 29.0, 0.0),
    "R7": (40.0, 42.5, 90.0),
    "R12": (52.0, 33.0, 0.0),
    "R13": (52.0, 30.0, 0.0),
    "J5": (78.0, 40.0, 0.0),
    # the bus: connector, protection, termination, transceiver, in that
    # order up one corridor. The protector's reference pad faces the
    # connector, so the discharge it diverts returns to the contact it came
    # from over the shortest path the geometry allows.
    "J2": (BUS_TERMINAL_X_MM, BOTTOM_ROW_Y_MM, 0.0),
    "D4": (BUS_CORRIDOR_X_MM, BUS_PROTECTOR_Y_MM, 270.0),
    "R10": (BUS_CORRIDOR_X_MM - 5.4, BUS_TERMINATION_Y_MM, 180.0),
    "R9": (BUS_CORRIDOR_X_MM + 5.4, BUS_TERMINATION_Y_MM, 0.0),
    "J7": (BUS_CORRIDOR_X_MM - BUS_LINK_X_OFFSET_MM,
           BUS_TERMINATION_Y_MM, 270.0),
    "J6": (BUS_CORRIDOR_X_MM + BUS_LINK_X_OFFSET_MM,
           BUS_TERMINATION_Y_MM, 90.0),
    "TP7": (BUS_CORRIDOR_X_MM - 6.5, 23.5, 0.0),
    "TP6": (BUS_CORRIDOR_X_MM + 6.5, 23.5, 0.0),
    "C20": (BUS_CORRIDOR_X_MM + BUS_LINK_X_OFFSET_MM + 2.54, 23.5, 90.0),
    "U2": (BUS_CORRIDOR_X_MM, BUS_TRANSCEIVER_Y_MM, 270.0),
    "C18": (BUS_CORRIDOR_X_MM - 3.5, BUS_TRANSCEIVER_Y_MM + 5.0, 0.0),
    "C19": (BUS_CORRIDOR_X_MM + 3.5, BUS_TRANSCEIVER_Y_MM + 5.0, 0.0),
    "R8": (BUS_CORRIDOR_X_MM + 6.0, BUS_TRANSCEIVER_Y_MM, 0.0),
    "TP8": (55.0, 33.0, 0.0),
    "TP9": (55.0, 29.5, 0.0),
    # the field connectors and the field supply path. The supply contact is
    # the one at the turned-round block's right-hand end, so the fuse that
    # feeds it stands to the right of the output columns and its conductor
    # crosses no channel.
    "J3": (OUTPUT_TERMINAL_X_MM, TOP_ROW_Y_MM, 180.0),
    "J4": (INPUT_TERMINAL_X_MM, TOP_ROW_Y_MM, 180.0),
    "F1": (36.5, 19.5, 90.0),
    "TP2": (FIELD_CORRIDOR_X_MM, 27.0, 0.0),
}


def to_board(x_mm, y_mm):
    return (ORIGIN_MM[0] + x_mm, ORIGIN_MM[1] - y_mm)


def _point(x_mm, y_mm):
    bx, by = to_board(x_mm, y_mm)
    return pcbnew.VECTOR2I(pcbnew.FromMM(bx), pcbnew.FromMM(by))


def accepted_placement():
    """The placement a search accepted, if one has been recorded.

    Absent, the seed below is the placement. Present, it replaces the seed
    for every part that is not locked - a locked part is locked in the board
    file and the search cannot have moved it, so accepting one from this file
    would be accepting a value that never came from a search.
    """
    if not os.path.isfile(PLACEMENT_PATH):
        return {}
    with open(PLACEMENT_PATH, encoding="utf-8") as handle:
        document = json.load(handle)
    return {reference: tuple(pose)
            for reference, pose in document["placement"].items()
            if reference not in LOCKED_REFERENCES}


def seed_placement():
    placed = dict(SHARED_PLACEMENT)
    for reference, (x, y) in MOUNTING_HOLES_MM.items():
        placed[reference] = (x, y, 0.0)
    for channel in range(1, netlist.OUTPUT_COUNT + 1):
        placed.update(_output_seed(channel))
    for channel in range(1, netlist.INPUT_COUNT + 1):
        placed.update(_input_seed(channel))
    return placed


def fixed_placements():
    placed = seed_placement()
    for reference, pose in accepted_placement().items():
        if reference not in placed:
            raise KeyError("accepted placement names an unknown part: "
                           + reference)
        placed[reference] = pose
    missing = sorted(reference for reference, part in netlist.PARTS.items()
                     if part["footprint"] and reference not in placed)
    if missing:
        raise KeyError("no placement for " + ", ".join(missing))
    return placed


def _footprint_dir(footprint):
    library, _, name = footprint.partition(":")
    for base in FOOTPRINT_SEARCH_PATHS:
        candidate = os.path.join(base, library + ".pretty")
        if os.path.isfile(os.path.join(candidate, name + ".kicad_mod")):
            return candidate, name
    raise FileNotFoundError(footprint)


_PIN_NAMES = {}


def _pin_name(lib_id, number):
    if lib_id not in _PIN_NAMES:
        library = ksym.Library(netlist.SYMBOL_LIBRARY_PATHS)
        _PIN_NAMES[lib_id] = {
            key: pins[0].name for key, pins in library.pins(lib_id).items()}
    return _PIN_NAMES[lib_id].get(number, "")


def _floating_net(board, reference, number):
    lib_id = netlist.PARTS[reference]["lib_id"]
    name = "unconnected-(%s-%s-Pad%s)" % (
        reference, _pin_name(lib_id, number).replace("/", "{slash}"), number)
    existing = board.GetNetInfo().GetNetItem(name)
    if existing is not None and existing.GetNetCode() != 0:
        return existing
    net = pcbnew.NETINFO_ITEM(board, name)
    board.Add(net)
    return net


def _load(board, reference, part, x, y, rotation, pin_net, nets):
    library_dir, name = _footprint_dir(part["footprint"])
    footprint = pcbnew.FootprintLoad(library_dir, name)
    if footprint is None:
        raise RuntimeError("could not load " + part["footprint"])
    library = part["footprint"].partition(":")[0]
    footprint.SetFPID(pcbnew.LIB_ID(library, name))
    footprint.SetPosition(_point(x, y))
    footprint.SetOrientationDegrees(rotation)
    footprint.SetReference(reference)
    footprint.SetValue(part["value"])
    footprint.Reference().SetLayer(pcbnew.F_Fab)
    footprint.Value().SetLayer(pcbnew.F_Fab)
    for key, value in (("MPN", part["mpn"]), ("LCSC", part["lcsc"]),
                       ("Manufacturer", part["manufacturer"])):
        if not value:
            continue
        footprint.SetField(key, value)
        for field in footprint.GetFields():
            if field.GetName() == key:
                field.SetLayer(pcbnew.F_Fab)
                field.SetVisible(False)
    if not part["in_bom"]:
        footprint.SetExcludedFromBOM(True)
    if reference in LOCKED_REFERENCES:
        footprint.SetLocked(True)
    for pad in footprint.Pads():
        number = pad.GetNumber()
        if not number:
            continue
        net_name = pin_net.get("%s.%s" % (reference, number))
        if net_name:
            pad.SetNet(nets[net_name])
        else:
            pad.SetNet(_floating_net(board, reference, number))
    board.Add(footprint)
    return footprint


def _nets(board):
    created = {}
    for name in sorted(netlist.NETS):
        net = pcbnew.NETINFO_ITEM(board, name)
        board.Add(net)
        created[name] = net
    return created


def _design_settings(board):
    board.SetCopperLayerCount(2)
    settings = board.GetDesignSettings()
    settings.m_TrackMinWidth = pcbnew.FromMM(0.15)
    settings.m_ViasMinSize = pcbnew.FromMM(0.45)
    settings.m_MinThroughDrill = pcbnew.FromMM(0.25)
    settings.m_CopperEdgeClearance = pcbnew.FromMM(EDGE_CLEARANCE_MM)
    settings.m_HoleClearance = pcbnew.FromMM(0.25)
    settings.m_HoleToHoleMin = pcbnew.FromMM(0.25)
    settings.m_ViasMinAnnularWidth = pcbnew.FromMM(0.1)
    settings.m_MinClearance = pcbnew.FromMM(CLEARANCE_MM)
    default_class = settings.m_NetSettings.GetDefaultNetclass()
    default_class.SetClearance(pcbnew.FromMM(CLEARANCE_MM))
    default_class.SetTrackWidth(pcbnew.FromMM(TRACK_WIDTH_MM))
    default_class.SetViaDiameter(pcbnew.FromMM(VIA_DIAMETER_MM))
    default_class.SetViaDrill(pcbnew.FromMM(VIA_DRILL_MM))


def _add_outline(board):
    corners = [(0.0, 0.0), (BOARD_W_MM, 0.0), (BOARD_W_MM, BOARD_H_MM),
               (0.0, BOARD_H_MM)]
    closed = corners + [corners[0]]
    for start, end in zip(closed, closed[1:]):
        shape = pcbnew.PCB_SHAPE(board)
        shape.SetShape(pcbnew.SHAPE_T_SEGMENT)
        shape.SetStart(_point(*start))
        shape.SetEnd(_point(*end))
        shape.SetLayer(pcbnew.Edge_Cuts)
        shape.SetWidth(pcbnew.FromMM(EDGE_WIDTH_MM))
        board.Add(shape)


def _rectangle_zone(board, corners, layers):
    zone = pcbnew.ZONE(board)
    layer_set = pcbnew.LSET()
    for layer in layers:
        layer_set.addLayer(layer)
    zone.SetLayerSet(layer_set)
    outline = zone.Outline()
    outline.NewOutline()
    for x, y in corners:
        bx, by = to_board(x, y)
        outline.Append(pcbnew.FromMM(bx), pcbnew.FromMM(by))
    return zone


def _pour(board, net, corners, layers, priority=0):
    zone = _rectangle_zone(board, corners, layers)
    zone.SetNet(net)
    zone.SetAssignedPriority(priority)
    zone.SetLocalClearance(pcbnew.FromMM(CLEARANCE_MM))
    zone.SetMinThickness(pcbnew.FromMM(0.2))
    zone.SetPadConnection(pcbnew.ZONE_CONNECTION_FULL)
    zone.SetThermalReliefGap(pcbnew.FromMM(0.3))
    zone.SetThermalReliefSpokeWidth(pcbnew.FromMM(0.4))
    board.Add(zone)
    return zone


def _keepout(board, corners, layers):
    """A rule area no track or via may enter.

    The bus pair's return path is a requirement, not a preference: a router
    that put one track across the ground under the pair would break it, and
    a board cannot be inspected afterwards for a hole that is only visible
    if you know to look. So the region is declared here and the design rule
    check enforces it.
    """
    zone = _rectangle_zone(board, corners, layers)
    zone.SetIsRuleArea(True)
    zone.SetDoNotAllowTracks(True)
    zone.SetDoNotAllowVias(True)
    zone.SetDoNotAllowZoneFills(False)
    zone.SetDoNotAllowPads(False)
    zone.SetDoNotAllowFootprints(False)
    board.Add(zone)
    return zone


def ground_outline():
    """The reference pour: the whole back layer, inset from the edge."""
    inset = ZONE_INSET_MM
    return [(inset, inset), (BOARD_W_MM - inset, inset),
            (BOARD_W_MM - inset, BOARD_H_MM - inset),
            (inset, BOARD_H_MM - inset)]


#: The protected input rail as one pour on the front layer, over the corner
#: the supply terminal, its clamp and its reservoir sit in and along the
#: converter row that ends at the resettable fuse. An L rather than a
#: rectangle because the rail's own parts stand in one, and a rectangle that
#: covered both arms would cover the controller as well.
INPUT_POUR_OUTLINE_MM = ((3.0, 3.0), (38.5, 3.0), (38.5, 21.0),
                         (25.0, 21.0), (25.0, 22.5), (3.0, 22.5))


def _add_pours(board, nets):
    _pour(board, nets[netlist.GROUND_NET], ground_outline(), (pcbnew.B_Cu,))
    _pour(board, nets[netlist.INPUT_RAIL_NET],
          list(INPUT_POUR_OUTLINE_MM), (pcbnew.F_Cu,), priority=1)
    for y0, y1 in BUS_KEEPOUT_SPANS_MM:
        x0 = BUS_CORRIDOR_X_MM - BUS_KEEPOUT_HALF_WIDTH_MM
        x1 = BUS_CORRIDOR_X_MM + BUS_KEEPOUT_HALF_WIDTH_MM
        _keepout(board, [(x0, y0), (x1, y0), (x1, y1), (x0, y1)],
                 (pcbnew.B_Cu,))
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

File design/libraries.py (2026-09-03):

"""The symbols and land patterns KiCad does not ship, generated from drawings.

Every dimension below is quoted from the package drawing named beside it, so
a reader can check the land pattern against the same document the footprint
was drawn from rather than against a remembered number. Where a vendor states
a recommended land pattern, that pattern is used; where none is stated, the
choice is this board's and says so.
"""
from __future__ import annotations

import os
import sys

REPO_ROOT = os.path.dirname(os.path.dirname(os.path.abspath(__file__)))
LIBRARY_NAME = "CanFdNode"
SYMBOL_LIB_PATH = os.path.join(REPO_ROOT, "library",
                               LIBRARY_NAME + ".kicad_sym")
FOOTPRINT_DIR = os.path.join(REPO_ROOT, "library", LIBRARY_NAME + ".pretty")
SYM_LIB_TABLE = os.path.join(REPO_ROOT, "sym-lib-table")
FP_LIB_TABLE = os.path.join(REPO_ROOT, "fp-lib-table")

SYMBOL_LIB_VERSION = "20251024"
FOOTPRINT_VERSION = "20260206"
GENERATOR = "can-fd-node-design-source"

# TI SLLSES7D table 6-1, D (SOIC) package, "V" suffix column: the level
# shifting supply replaces the no-connect at pin 5, which is the only
# difference from the non-V devices and the reason this part was chosen.
TRANSCEIVER_SYMBOL_NAME = "TCAN1042HGV"
TRANSCEIVER_PINS = [("1", "TXD", "input", "left"),
                    ("4", "RXD", "output", "left"),
                    ("8", "STB", "input", "left"),
                    ("3", "VCC", "power_in", "top"),
                    ("5", "VIO", "power_in", "top"),
                    ("2", "GND", "power_in", "bottom"),
                    ("7", "CANH", "bidirectional", "right"),
                    ("6", "CANL", "bidirectional", "right")]
TRANSCEIVER_DATASHEET = "https://www.ti.com/lit/ds/symlink/tcan1042h.pdf"

# MPS MP2459 Rev. 1.1, pin functions table: TSOT23-6 is BST, GND, FB, EN, IN,
# SW on pins 1 to 6.
CONVERTER_SYMBOL_NAME = "MP2459"
CONVERTER_PINS = [("5", "IN", "power_in", "left"),
                  ("4", "EN", "input", "left"),
                  ("3", "FB", "input", "left"),
                  ("1", "BST", "passive", "right"),
                  ("6", "SW", "output", "right"),
                  ("2", "GND", "power_in", "bottom")]
CONVERTER_DATASHEET = ("https://datasheet.lcsc.com/datasheet/pdf/"
                       "2304140030.pdf")

# Holtek HT75Rxx-1 Rev. 1.01, pin diagram: SOT89 is GND, VIN, VOUT on pins
# 1, 2, 3. The regulator output is the only source on the logic rail, so it
# is declared power_out and that rail carries no separate power flag.
REGULATOR_SYMBOL_NAME = "HT75Rxx-1"
REGULATOR_PINS = [("2", "VIN", "power_in", "left"),
                  ("3", "VOUT", "power_out", "right"),
                  ("1", "GND", "power_in", "bottom")]
REGULATOR_DATASHEET = ("https://datasheet.lcsc.com/datasheet/pdf/"
                       "59abfa7ca0c1b0cd081d8e8f60c28ed0.pdf")

# ST DS12789 Rev 2, front-page internal schematic: two bidirectional
# suppressors from pins 1 and 2 to the common pin 3.
BUS_PROTECTOR_SYMBOL_NAME = "ESDCAN05-2BWY"
BUS_PROTECTOR_PINS = [("1", "IO1", "passive", "left"),
                      ("2", "IO2", "passive", "left"),
                      ("3", "GND", "passive", "bottom")]
BUS_PROTECTOR_DATASHEET = ("https://www.st.com/resource/en/datasheet/"
                           "esdcan05-2bwy.pdf")

# NCE6003X marking and pin assignment figure, SOT-23 top view: gate 1,
# source 2, drain 3.
BLOCKING_FET_SYMBOL_NAME = "NCE6003X"
BLOCKING_FET_DATASHEET = ("https://wmsc.lcsc.com/wmsc/upload/file/pdf/v2/"
                          "lcsc/2201121630.pdf")

# WST6066A SOT-23-3L pin configuration figure: gate and source on the two-pin
# side, drain opposite, which is the same numbering.
OUTPUT_FET_SYMBOL_NAME = "WST6066A"
OUTPUT_FET_DATASHEET = ("https://datasheet.lcsc.com/datasheet/pdf/"
                        "fa81b0d9ae88480fa681d4eacf953c2b.pdf")

FET_PINS = [("1", "G", "input", "left"),
            ("2", "S", "passive", "bottom"),
            ("3", "D", "passive", "top")]

# DORABO DB128V-5.08-XXP-C-S customer drawing, 2022-10-27, rev T0-1: PCB hole
# diameter 1.60, pitch 5.08, pin 0.80 x 1.00, body N x 5.08 long by 10.20
# deep by 14.00 high, standing 3.50 off the board. The drawing states the
# hole but no annulus, so the 0.50 ring below is this board's choice.
TERMINAL_FAMILY = "DB128V-5.08"
TERMINAL_PITCH_MM = 5.08
TERMINAL_DRILL_MM = 1.60
TERMINAL_PAD_DIAMETER_MM = 2.60
TERMINAL_BODY_DEPTH_MM = 10.20
TERMINAL_PIN_TO_ENTRY_FACE_MM = 5.00
TERMINAL_COURTYARD_MARGIN_MM = 0.25
TERMINAL_POSITIONS = (2, 3, 5)

# YXC YSX531SL, "Recommended Land Pattern": four 2.0 x 1.2 pads with a 1.7
# horizontal gap and a 1.0 vertical gap, so centres lie on 3.7 by 2.2. Body
# 5.00 x 3.20 x 0.9 max. Pads 1 and 3 are the crystal, 2 and 4 the case.
CRYSTAL_FOOTPRINT_NAME = "Crystal_YXC_YSX531SL_5.0x3.2mm"
CRYSTAL_PAD_MM = (2.0, 1.2)
CRYSTAL_PAD_PITCH_MM = (3.7, 2.2)
CRYSTAL_BODY_MM = (5.0, 3.2)
CRYSTAL_COURTYARD_MARGIN_MM = 0.25

# Sunlord SWPA series catalogue (revised 2023/06/01), external dimensions
# table: the 5040 body is 5.0 x 5.0 x 4.0. The catalogue's land pattern is a
# figure rather than a dimensioned drawing, so the pads below are this
# board's choice: two 1.8 x 4.2 lands on 4.4 centres, which covers the
# terminations of a 5 x 5 wire-wound part with the usual 0.3 toe.
INDUCTOR_FOOTPRINT_NAME = "Inductor_Sunlord_SWPA5040"
INDUCTOR_PAD_MM = (1.8, 4.2)
INDUCTOR_PAD_PITCH_MM = 4.4
INDUCTOR_BODY_MM = (5.0, 5.0)
INDUCTOR_COURTYARD_MARGIN_MM = 0.25

# LUTE 1812L series, dimension table: body 4.37-4.73 long by 3.07-3.41 wide,
# pad width 0.60-1.50 with a 0.30 to 0.20 gap. The series states no
# recommended land pattern, so the two 1.80 x 3.40 lands on a 3.20 gap below
# are this board's choice, sized to cover the widest body and the longest
# termination.
PTC_FOOTPRINT_NAME = "PTC_1812_LUTE_1812L"
PTC_PAD_MM = (1.80, 3.40)
PTC_PAD_GAP_MM = 3.20
PTC_BODY_MM = (4.73, 3.41)
PTC_COURTYARD_MARGIN_MM = 0.25

# The five connectors, drawn with their functions on the pins rather than as
# numbered generic terminals. The board's contract is which contact carries
# what - the brief fixes the bus pair's position, and a plug that mates
# mechanically but not in this order damages what it is wired to - so the
# order is on the symbol where a reader sees it, not only in a table.
CONNECTOR_SYMBOLS = {
    "SupplyInput_1x02": ["V24_IN", "RETURN"],
    "BusConnector_1x03": ["CAN_GND", "CANL", "CANH"],
    "OutputConnector_1x05": ["VFIELD", "DO1", "DO2", "DO3", "DO4"],
    "InputConnector_1x05": ["GND", "DI1", "DI2", "DI3", "DI4"],
    "DebugHeader_1x05": ["+3V3", "SWDIO", "SWCLK", "NRST", "GND"],
}

# A termination link: one leg of the split termination passes through it, and
# there is one on each side of the bus pair. Two headers rather than one is
# what keeps either leg from having to cross the pair to reach the other.
TERMINATION_LINK_SYMBOL_NAME = "TerminationLink_1x02"
TERMINATION_LINK_PINS = ["LEG", "SPLIT"]
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

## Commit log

2026-08-30 Seed benchmark board 06/32 from its supplied brief
    PCBA_CAN_FD_Node is one of thirty-two boards in the PCBA_AutoDesignAndTest
    benchmark. This commit establishes the repository and nothing else:
    the board is not designed, and its absence is the intended state.
    BRIEF.md is the supplied brief, preserved byte for byte and
    authoritative. board/requirements.json splits it into fixed_requirements
    -- each carrying the verbatim brief text that substantiates it, bound to
    the SHA-256 of the brief's bytes -- and open_decisions, which are the
    design agent's to make and to record as choices. Promoting a decision
    into a requirement is the failure the split exists to prevent.
    docs/architecture.md is a wor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
2026-08-30 Stop the scaffold claiming a check it does not perform
    An external review of the pushed benchmark found this repository asserting
    three things about itself that were not true as shipped.
    board/manifest.template.json said running the validator against it "will
    fail on the missing source". It does not: `run.py validate
    board/manifest.template.json` exits 0 and prints ACCEPTED, with all 36 gates
    NOT_APPLICABLE and no gate reading sources.pcb, so the absent board file is
    never noticed. The template now says exactly that, under verdict_warning,
    and docs/status.md and CLAUDE.md carry the same warning where a reader and
    an agent will actually meet it. The toolkit is behaving as designed - a gate
    w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
2026-08-30 Remove the claim-audit skill, and the instructions that called it
    Requested. .claude/skills/claim-audit/ is deleted, and with it every
    reference: CLAUDE.md's publishing discipline no longer names it, and the
    README layout table no longer advertises it.
    accountability-review kept calling it at step 3, which would have left the
    surviving skill invoking one that is not in the clone - the same
    dangling-instruction defect that put these skills in the repository in the
    first place. That step now states the claim-binding work directly: scan the
    drafts for claim-bearing words, and bind each to an artifact recomputed on
    the spot rather than to the process that produced it. The discipline is
    unchange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
2026-08-30 Finish removing claim-audit: the last prose reference to it
    accountability-review still explained itself with "that is why the claim
    audit runs first". Nothing runs first any more - the claim binding is step 3
    of this skill, and it runs before the review package is assembled, not
    before the review. The sentence now says that.
    Removing a skill is not done when its file is gone. It is done when nothing
    left in the repository tells a reader to go and find it.
2026-08-30 Review against this repository's own invariants, not another board's
    /accountability-review assembled its review package with a hardcoded list
    of "standing invariants", and that list belonged to a different project and
    an abandoned workflow: "never modify the authoritative Board A PCB" names a
    board that does not exist here, and "never touch main" and "no PRs"
    describe a process the opposite of this one -- every repository in this
    benchmark is developed on main and pushed directly.
    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
2026-08-30 Delete generated prose; keep the seed brief and machine-consumed config
    The seed pack already contained the human-authored specification for this
    board. Everything this repository added on top was a reinterpretation of it:
    a README and CLAUDE.md narrating the brief, an architecture worksheet of
    English questions, status and sources documents, a prose requirements
    document, and requirements.json - which restated the brief as English
    requirement strings and copied 20-odd verbatim quotations back out of a file
    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
2026-09-03 Design the CAN FD node from its brief to a fabricable board
    The node takes 18-30 V field power, drives four low-side outputs and reads
    four field inputs, and sits on a CAN FD bus it may terminate.
    Three orderings decide the board. The bus meets its contacts, then its
    protection, then its termination, then the transceiver, and the pair keeps
    one spacing over an unbroken return the whole way: the return is closed to
    every other conductor under the pair, with windows only where the design
    source itself crosses. The reverse-blocking device sits in the return
    rather than the supply, so the bus connector's reference pin is the board's
    own reference and not a node that floats when the supply is re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
    [bom.csv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]
2026-09-03 Record what this board needed from the toolkit and did not have
2026-09-03 Rebind the release to the phase 0 toolkit
    The toolkit now validates every manifest against its published schema
    and refuses vocabulary it does not implement, so the board-local gate
    list moves under the x_ extension prefix; gate-class selection
    (--only=design) supersedes it. Regenerated and revalidated against
    toolkit f4d3904: 22 gates pass, 14 report NOT_APPLICABLE, and
    the fabrication record now carries the source-closure member map, so
    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
    [can_fd_node-B_Cu.gbr, can_fd_node-B_Mask.gbr, can_fd_node-B_Silkscreen.gbr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]
2026-09-03 Retire the hand-written routing acceptance list
    The toolkit's design gate class replaces it: candidate acceptance now
    selects --only=design, expanded by the toolkit, so the set cannot rot
    as gates are added. The list leaves the manifest and the generator that writes it, and the
    release is regenerated under toolkit b441685, which also closes the
    review findings on the phase 0 seams: 22 gates pass, 14 report
    NOT_APPLICABLE.
    [can_fd_node-B_Cu.gbr, can_fd_node-B_Mask.gbr, can_fd_node-B_Silkscreen.gbr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]
2026-09-03 Close the adversarial findings that reached this board
    The unread keys the manifest carried are gone: tolerance_seconds is
    deleted, contact_semantics becomes the note annotation it always was,
    and the schema now refuses both by name. The routing acceptance
    selection regains ROUTE.PROVENANCE - the loop writes the record before
    judging, so record-board agreement is judged per candidate as it was
    under the hand-written list. Regenerated and revalidated under
    toolkit a0f53eb: 22 gates pass, 14 report NOT_APPLICABLE.
    [can_fd_node-B_Cu.gbr, can_fd_node-B_Mask.gbr, can_fd_node-B_Silkscreen.gbr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]
2026-09-03 Rebind the release to toolkit 0c051f2
    The toolkit keeps its CLI alive with no display and closes the third
    review round's findings; nothing in this board's own sources moved.
    22 gates pass, 14 report NOT_APPLICABLE.
    [can_fd_node-B_Cu.gbr, can_fd_node-B_Mask.gbr, can_fd_node-B_Silkscreen.gbr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]
2026-09-03 Rebind the release to toolkit 7f51066
    The panel-fix round widened the source closure to every staged design
    input and hardened the verdict binding, so the fabrication outputs and
    the recorded verdict are regenerated under the new toolkit. The
    transient .pcbqa-hold-* lock file is ignored.
    [can_fd_node-B_Cu.gbr, can_fd_node-B_Mask.gbr, can_fd_node-B_Silkscreen.gbr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]
2026-09-04 Delete the routing loop, declare the search, rebind to toolkit bd0ad78
    The 704-line private loop moves to the toolkit; the declaration is
    generated by design/manifest.py, reserving the pours, the bus pair,
    the field outputs and the termination centre exactly as the deleted
    expression did. layout.write() saves through the project-preserving
    save and the clobber-repair write_project() call is deleted - its
    docstring stated that rationale, and the repair is now structural.
    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
    [can_fd_node-B_Cu.gbr, can_fd_node-B_Mask.gbr, can_fd_node-B_Silkscreen.gbr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]
2026-09-04 Drop the attempt budget to the distinct matrix, and refresh the binding
    The toolkit's review round closed the identical-attempts channel: the
    router is invoked deterministically per row, so attempts above the
    distinct orderings x clearances matrix are refused rather than cycled.
    This board declared 9 attempts over 3 distinct rows - the old private
    loop's repeat-3x budget - which now refuses at `route --check`. The
    declaration drops to its 3 distinct rows; nothing about the committed
    copper changes.
    The rebuild refreshes fabrication.json's toolkit identity and closure
    under the reviewed toolkit; the deterministic exports are byte-stable.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
    [manifest.py]
2026-09-04 Accept through the design gate class; declare courtyards; drop route.py
    The re-review held the plan to its words: "routing accepts nothing
    release will reject" means the acceptance names the design gate
    class, not a counter subset - so it now does, beside the counters.
    placement.courtyard is declared for both faces (edge clearance is
    not: this board places connectors or mounting holes at its outline
    by design, and reports that reason instead of promising a margin).
    design/route.py is deleted per the plan; `run.py route` is the
    entry. Fabrication binding refreshed under the reviewed toolkit.
    [manifest.py]
2026-09-04 Write the placement board through the project-preserving save
    The toolkit review's Phase 1.6 sweep found this board's unused
    placement-writer helper still calling pcbnew.SaveBoard directly -
    which rewrites, or invents, sibling project documents beside whatever
    path it is given. `write_placement_board` now goes through
    `pcbqa.board.save` like every other board write, and a test pins that
    no design module calls SaveBoard directly again. Revalidated under
    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
2026-09-05 Refresh the fabrication binding under the reviewed toolkit
    The toolkit's fourth review round pinned the routing judgment to its
    recorded policy at the read site, fixed the router-summary shape the
    reconciliation reads, and extended post-adoption enforcement to the
    manifest digest and recorded plan; nothing in this board's own sources
    changed. Rebuilt and revalidated so the committed verdict and closure
    name the reviewed toolkit state.
2026-09-05 Refresh the fabrication binding under the reviewed toolkit
    The toolkit's fifth review round closed its last blocker: with a
    recorded binding declared, every acceptance gate now reads the
    verified staged design instead of live pathnames. Nothing in this
    board's own sources changed. Rebuilt and revalidated so the committed
    verdict and closure name the reviewed toolkit state.
2026-09-05 Refresh the fabrication binding under the reviewed toolkit
    The toolkit's sixth review round bound every auxiliary file the
    routing acceptance gates consume - stackup supplements, contract
    documentation, simulation records - into the routing record, enforced
    at adoption, check, provenance and replay; nothing in this board's
    own sources changed. Rebuilt and revalidated so the committed verdict
    and closure name the reviewed toolkit state.
2026-09-05 Author the requirement register: 67 requirements stop citing bare BRIEF.md
    Every requirement name this board's 225 claims are judged against is
    now registered with its kind - six the brief states, most derived from
    frozen datasheets with their rationale, and the bounds this design
    chose (the quarter-of-the-difference dissipation margin, the 5 percent
    termination window, the tenth-of-a-picofarad balance, the input
    thresholds' floor and hysteresis, the capacitance and oscillator
    budgets) recorded as design decisions with the alternatives they were
    chosen over. The two choices the brief left open - MCU/transceiver,
    and manual-versus-MCU termination switching - are closed on the record
    as statem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
    [extraction.py, requirements.py, rules.py]
2026-09-05 Refresh the fabrication binding under the committed Phase 2 toolkit
    The toolkit's evidence-governance commit is a source-closure member,
    so the committed artifacts and verdict re-bind to it. Nothing in this
    board's own sources changed in this commit.
2026-09-05 Move the governance declarations into the manifest generator
    The board's own committed-manifest-is-generated test caught what the
    finishing pipeline had swallowed: the Phase 2 manifest blocks were
    scripted onto board/manifest.json while design/manifest.py still
    generated the old document. The blocks now live in design/governance
    as data the generator merges, the evidence index gains its new frozen
    entry through design/evidence.py rather than by hand, the committed
    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
2026-09-05 Adopt the round-2 review corrections: expiring dependencies, one registry assembly
    Open external dependencies gain review dates, and
    design/extraction.py stops reimplementing the gate registry assembly
    - simulation_models and the new simulation_registry delegate to
    pcbqa.sim.assemble, so C4 is finally closed by deletion: the physical
    inputs a local run validates are the same committed records the gate
    validates, by construction.
    [extraction.py, governance.py, test_design.py]
2026-09-05 Adopt the round-3 corrections: the claim document joins the closure
    The claim document the verdict rests on joins the source closure, so
    a release tag carries it and its movement is a named staleness. The
    claims generator declaration is now mandatory toolkit-side
    (CLAIM.MATRIX refuses an unlisted document), which this board already
    satisfied.
    [governance.py]
2026-09-05 Refresh the fabrication binding: round-3 verdict rendering
    The toolkit's open-item rendering commit is a closure member; this
    board's committed verdict re-binds to it. No board sources changed.
2026-09-05 Refresh the fabrication binding: fourth-round evidence fixes
    The toolkit now lists register methods still required that no
    dependency owns as open items in the policy state - a passing claim
    establishes the number, never the separately declared method - and the
    refreshed validation record carries whatever this board honestly owes.
2026-09-05 Refresh the fabrication binding: fifth-round toolkit
    Domain enforcement now owns timing's evidence gates, refuses vacuous
    simulation declarations, and judges device-parameter validity from the
    operating point; nothing on this board changes beyond the closure.
2026-09-05 Refresh the fabrication binding: sixth-round toolkit
    PROV.DEVICE_PARAMETERS now judges applicability from the citation
    rather than from the presence of a validity range - a record with no
    stated range has no supported range. Nothing on this board changes
    beyond the closure; its citations already state their operating points.
2026-09-05 Re-freeze against the advanced fabricator catalogue
    Phase 3.1 published seven more capabilities from the SAME frozen
    evidence - hole plating thickness, the PTH annular ring, and the
    soldermask process set - so the approved catalogue's normalized digest
    moved from 953f02ea to e504b0de. Every physical input this board froze
    records the catalogue state it was resolved from, so those records were
    re-frozen against the current one.
    Nothing this board selects changed: the process selection came back
    byte-identical apart from the digest, and no physical value moved. The
    new capabilities describe plating and soldermask, which this board's
    selection does not turn on.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
2026-09-05 Decide, on the record, about the five domains Phase 3 added
    Phase 3 implements thermal, current capacity, power integrity,
    differential pair and reference continuity as evidence domains, so
    saying nothing about them is no longer a neutral act: silence lands the
    policy state on requires-additional-evidence.
    This board declines all five, each with a reason true of THIS board -
    what it does instead, or why the domain does not describe it. It cannot
    honestly declare them: declaring one means authoring a capacity basis, a
    set of thermal-resistance records or a rail mesh, and inventing any of
    that is precisely the fabrication this toolkit exists to prevent. Where
    the board already answers the que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
    [governance.py]
2026-09-05 Refresh the fabrication binding against the reviewed Phase 3 toolkit
    The toolkit is a source-closure member, so four rounds of adversarial
    review over Phase 3 mean the committed reports and the validation record
    are re-made against the code that now exists. Nothing about this board
    changed.
2026-09-06 Rebuild the artifacts against the fifth-review toolkit
    No verdict moves and no gate changes status: the round closed defects in
    the current, PDN, coverage and arc paths, and what this board exercises
    of them it already exercised correctly. The artifacts are refreshed so
    the recorded run names the toolkit commit that produced it rather than
    one four fixes behind.
2026-09-06 Judge the vias against the process, the pair against its reference, and three packages at 60 C
    Six gates the toolkit grew while this board was not asking for them.
    VIA.MASK_CLEARANCE_PROCESS and VIA.NATIVE_GERBER_AGREEMENT cost one
    catalogue pin and one process clause. The vias are now judged against
    JLCPCB's published 0.09 mm soldermask-opening-to-copper clearance as
    well as this board's own tighter 0.15 mm target, and each of the 131 is
    compared object by object with the Gerber the fabricator will receive.
    The pin is read from the approved snapshot rather than typed, so it
    cannot cite a catalogue state the fabrication was never selected under.
    NET.REFERENCE_CONTINUITY is the check the bu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
    [governance.py, manifest.py, test_design.py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]
2026-09-06 State each theta record's regime on the record
    The toolkit now refuses a thermal resistance that does not say whether
    it is a steady-state or a transient figure, because everything it
    derives is a CONTINUOUS statement and a transient resistance silently
    used as one understates every rise - the exact trap board 03 found on a
    driver datasheet. Every figure this board records under a theta_ja key
    is a junction-to-ambient RESISTANCE, defined at thermal equilibrium; a
    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
2026-09-06 Rebuild the artifacts against the review-response toolkit
    No verdict moves and no gate changes status. The round closed the
    island-barrel channel in the PDN mesh, scoped the thermal copper
    ceiling to a named pad, and corrected two verdict texts; what this
    board exercises of them it already exercised correctly, and the refresh
    binds the record to the toolkit commit that produced it.
2026-09-06 Rebuild the artifacts against the second-pass toolkit
    No verdict moves and no gate changes status. The pass closed the
    untested through-hole half of the island-barrel filter and composed
    every standing THERMAL.DERATING problem into its verdict; what this
    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
2026-09-06 Rebuild the artifacts against the fragility-knob toolkit
    No verdict moves and no gate changes status. The toolkit pins
    KICAD_PLANE_FRAGILITY_COST=0 for every FUTURE owned search - KiCad's
    zone filler is a thread race the field inherited, core pinning
    measurably does not close it, and disabling the field is deterministic
    by construction. This board's adopted route and record are untouched:
    the knob binds searches, not validations, and a replay of the old
    record now refuses the environment check as it should. The refresh
    binds the artifacts to the toolkit commit that produced them.
2026-09-07 Rebuild the artifacts against the fill-oracle-account toolkit
    No verdict moves and no gate changes status. The wrapper now refuses a
    router summary that cannot account for which pour geometry its
    fragility field used; this board's adopted route and record are
    untouched, and the refresh binds the artifacts to the toolkit commit
    that produced them.
2026-09-07 Rebuild the artifacts against the upstream-merged toolkit
    No verdict moves and no gate changes status. The pinned router advanced
    through 254 upstream commits (grid_router v0.22.0, the #831 fill-oracle
    account the wrapper now reads, the --clearance semantics split); this
    board's adopted route and record are untouched, future searches inherit
    the new semantics, and the refresh binds the artifacts to the toolkit
    commit that produced them.
2026-09-11 Retire this board's toolkit request file
    Removed at the operator's direction. The program rule is that a request
    is closed by deletion rather than by a status note, and the toolkit
    work these asked for has been landing across phases 0 to 4; the files
    themselves stay readable in this repository's history, which is where a
    closed request belongs.
2026-09-11 Decide the two domains Phase 4 added, and judge the oven against the datasheets
    Phase 4 adds `lifecycle` and `assembly_process` to the toolkit's domain
    vocabulary, and a board that mentions neither has decided nothing about
    either - which is how the policy record read before this change: two
    domains `absent`, so the board could not have returned to
    fabrication-ready even after the toolkit rebuild.
    `assembly_process` is declared. The process is the board's own build
    definition: one lead-free reflow pass at a peak of no more than 245 C,
    top side only, no-clean, with the seven through-hole connectors
    hand-soldered after reflow. 245 C is below every reflowed part's own
    stated tolerance with 15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
    [can_fd_node-B_Cu.gbr, can_fd_node-B_Mask.gbr, can_fd_node-B_Silkscreen.gbr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]
2026-09-12 The Bus class judged nothing, and the search no longer reproduces this board
    Phase 5's two board-facing gates, and what they found here.
    DRC.NETCLASS_COHERENCE found a live defect. The project declared the
    Bus class's membership through the in-class `nets` list - the KiCad 6
    shape - which `kicad-cli pcb drc` silently ignores. CANH and CANL
    resolved to Default on the DRC path, so the pair the whole bus
    argument rests on was judged at 0.15 mm clearance and 0.25 mm track
    width, not the 0.2/0.3 the class states: the design rule was less
    strict in practice than the project said, and had been since the class
    was written. design/build.py now declares membership in
    `netclass_assignments`, the chann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
    [can_fd_node-B_Cu.gbr]
